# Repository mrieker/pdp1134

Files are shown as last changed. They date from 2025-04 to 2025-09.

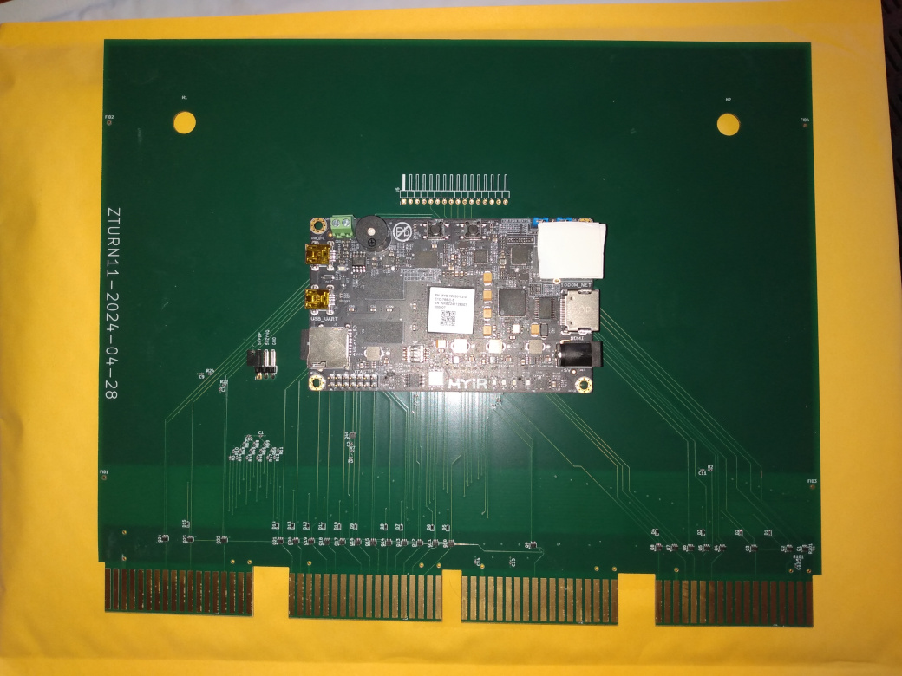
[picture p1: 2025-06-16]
boardpic.jpg

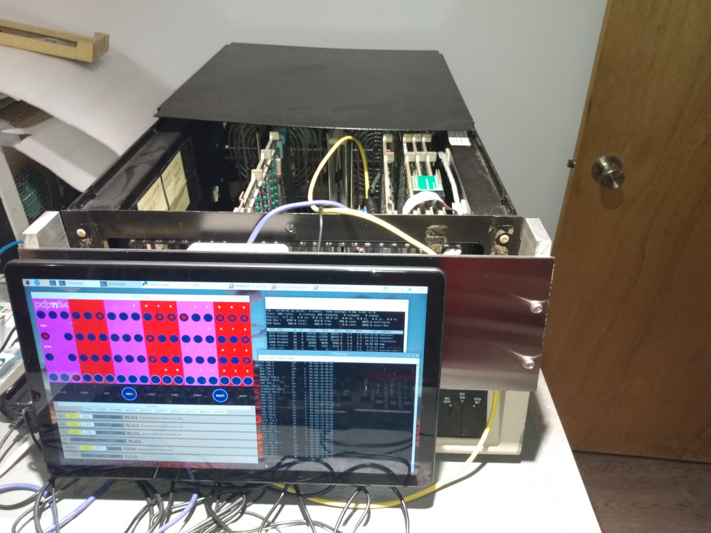
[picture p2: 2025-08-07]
runningpic.jpg

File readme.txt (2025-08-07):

FPGA/ARM board that plugs into Unibus on PDP-11/34.

Provides functionality of the KY-11 console, 124KW memory,
RL-11 disks (RL01/RL02), DL-11 serial port, KW-11 line clock,
RH-11 disks (RP04/RP06), TM-11 tape drive, DELUA ethernet,
PC-11 paper tape reader/punch, DZ-11 serial line mux.

Also contains a PDP-11/34 processor simulator so can test
software without having real processor.

Has a GUI interface (ccode/z11gui) as well as a TCL command line
interface (ccode/z11ctrl) for scripting.

See howto.txt for more information.

Pics of board and gui screen are in boardpic.jpg and guittypic.png,
runningpic.jpg is pic of 10.5" screen mounted on front of PDP-11/34
with Zynq in place of console board.

It uses a ZTurn Zynq 7020 board for the FPGA/ARM processor,
memory, SDCARD, ethernet.  The ARM processor runs the
Raspberry PI OS, with a kernel specific to the Zynq.

The board might work on other PDP-11s, I haven't tested it
with anything else.  The only thing that makes it '34 specific
are the two halt signals.  Other than that, it is just another
Unibus compatible device, fitting in a quad-sized SPC slot.

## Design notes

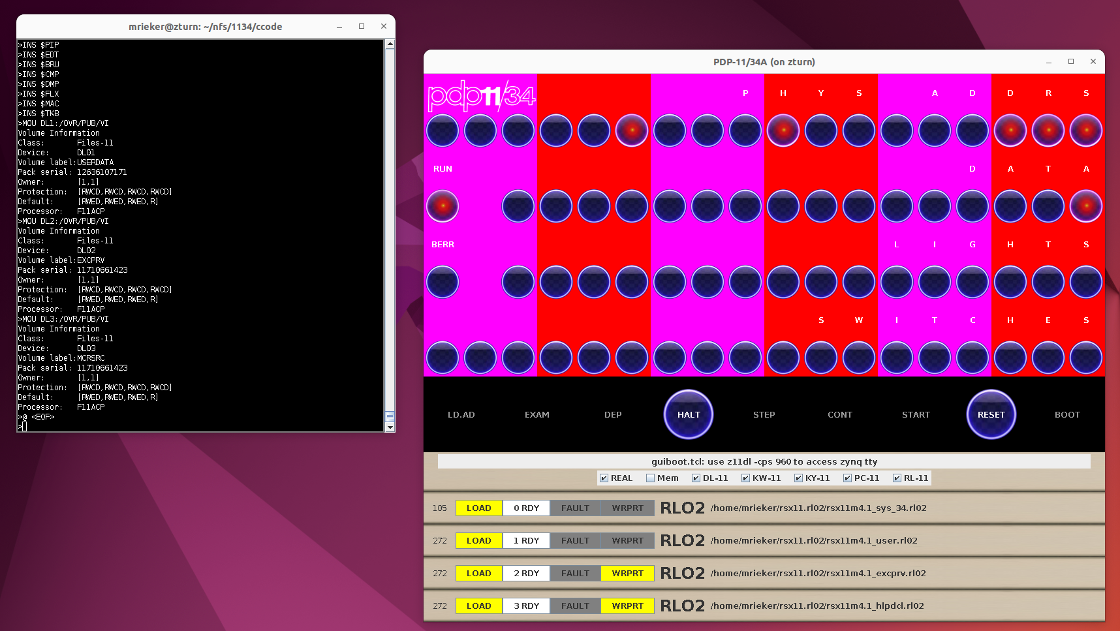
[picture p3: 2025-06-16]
guittypic.png

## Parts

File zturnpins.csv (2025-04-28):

J11-09 | B13-LN11 | V7
J11-13 | B13-LN12 | U10
J11-19 | B13-LN13 | Y6
J11-18 | B13-LN14 | Y8
J11-23 | B13-LN15 | W8
J11-22 | B13-LN21 | V10
J11-07 | B13-LP11 | U7
J11-11 | B13-LP12 | T9
J11-17 | B13-LP13 | Y7
J11-16 | B13-LP14 | Y9
J11-21 | B13-LP15 | V8
J11-20 | B13-LP21 | V11
J11-28 | B34-LN01 | T10
J11-29 | B34-LN02 | U12
J11-32 | B34-LN03 | V13
J11-33 | B34-LN04 | W13
J11-38 | B34-LN05 | T15
J11-39 | B34-LN06 | R14 | LED-RED
J11-42 | B34-LN07 | Y17 | LED-BLU
J11-43 | B34-LN08 | Y14
J11-47 | B34-LN11 | U15
J11-26 | B34-LP01 | T11
J11-27 | B34-LP02 | T12
J11-30 | B34-LP03 | U13
J11-31 | B34-LP04 | V12
J11-36 | B34-LP05 | T14
J11-37 | B34-LP06 | P14
J11-40 | B34-LP07 | Y16 | LED-GRN
J11-41 | B34-LP08 | W14
J11-45 | B34-LP11 | U14 | 12MHz OSC
J12-25 | B35-LN01 | B20
J12-24 | B35-LN02 | A20
J12-29 | B35-LN03 | D18
J12-28 | B35-LN04 | D20
J12-35 | B35-LN05 | E19
J12-34 | B35-LN06 | F17
J12-39 | B35-LN07 | M20
J12-38 | B35-LN08 | M18
J12-45 | B35-LN09 | L20
J12-44 | B35-LN10 | J19
J12-49 | B35-LN11 | L17
J12-48 | B35-LN12 | K18
J12-55 | B35-LN13 | H17
J12-54 | B35-LN14 | H18
J12-59 | B35-LN15 | F20
J12-58 | B35-LN16 | G18
J12-65 | B35-LN17 | H20
J12-64 | B35-LN18 | G20
J12-69 | B35-LN19 | G15
J12-68 | B35-LN20 | J14
J12-75 | B35-LN21 | N16
J12-74 | B35-LN22 | L15
J12-79 | B35-LN23 | M15
J12-78 | B35-LN24 | J16
J12-23 | B35-LP01 | C20
J12-22 | B35-LP02 | B19
J12-27 | B35-LP03 | E17
J12-26 | B35-LP04 | D19
J12-33 | B35-LP05 | E18
J12-32 | B35-LP06 | F16
J12-37 | B35-LP07 | M19
J12-36 | B35-LP08 | M17
J12-43 | B35-LP09 | L19
J12-42 | B35-LP10 | K19
J12-47 | B35-LP11 | L16
J12-46 | B35-LP12 | K17
J12-53 | B35-LP13 | H16
J12-52 | B35-LP14 | J18
J12-57 | B35-LP15 | F19
J12-56 | B35-LP16 | G17
J12-63 | B35-LP17 | J20
J12-62 | B35-LP18 | G19
J12-67 | B35-LP19 | H15
J12-66 | B35-LP20 | K14
J12-73 | B35-LP21 | N15
J12-72 | B35-LP22 | L14
J12-77 | B35-LP23 | M14
J12-76 | B35-LP24 | K16
J11-51 | LCD-DATA00 | T16
J11-53 | LCD-DATA01 | U17
J11-46 | LCD-DATA02 | V15
J11-48 | LCD-DATA03 | W15
J11-55 | LCD-DATA04 | U18
J11-57 | LCD-DATA05 | U19
J11-50 | LCD-DATA06 | N18
J11-52 | LCD-DATA07 | P19
J11-59 | LCD-DATA08 | N20
J11-61 | LCD-DATA09 | P20
J11-56 | LCD-DATA10 | T20
J11-58 | LCD-DATA11 | U20
J11-63 | LCD-DATA12 | V20
J11-65 | LCD-DATA13 | W20
J11-60 | LCD-DATA14 | Y18
J11-62 | LCD-DATA15 | Y19
J11-64 | LCD-DE | R16
J11-69 | LCD-HSYNC | W16
J11-66 | LCD-PCLK | R17
J11-70 | LCD-VSYNC | V16

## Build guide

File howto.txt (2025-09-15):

Basic configurations:

    1) real without console -
        KY-11 console M7859 removed (leds dark but power switch works)
        ZTurn plugged into primary backplane (so it has access to halt lines)
        All console functions handled via GUI or TCL commands

    2) real with console -
        KY-11 console M7859 installed
        ZTurn connected to Unibus theoretically anywhere
        Only RESET and BOOT functions available via GUI and TCL
        All other console functions handled via KY-11 keypad

    Simulator will work with either of the above configurations.  It
    will ignore anything coming in from the Unibus and not output
    anything to the Unibus.  It will run with the processor power on
    or off, and will run on a ZTurn board not plugged into anything.

--------

Quickstart guide:

    Set up SDCARD for ZTurn board:

        see zplin/quicksdcard.txt

        * copy 32-bit raspi os to an SD card
        * delete all files from /boot partition then replace with
            just BOOT.BIN and image.ub from the zynq directory
        * boot zturn and configure to taste

        * clone repo to non-priv user (sudo should not require password)
        * cd 1134/ccode ; make

    These instructions apply only if the M7859 console board is installed and working:

        Use z11ctrl command to load media files in FPGA provided drives:

        $ ./z11ctrl
        z11ctrl> source $Z11HOME/boots.tcl  ;# get some boot related functions
        z11ctrl> pin set fpgamode 2         ;# connect FPGA to real Unibus
        z11ctrl> probedevsandmem            ;# turn on fpga devices and memory to fill in missing real devices and memory
        z11ctrl> rlload 0 somefile.rl02     ;# load a file in RL02 drive 0 (will also accept .rl01 files)
                                            ;# there is also rhload (RP04/RP06) and tmload (TU10)

        Then use the 11/34 keypad to boot the disk.
        If the boot rom does not contain RL boot code:

        z11ctrl> rlboot                     ;# or rhboot, tmboot

        Either way, if the Z11 is providing the console tty:

        z11ctrl> exit
        $ ./z11dl

    These instructions apply only if there is no M7859 console board installed:

        To boot the 11/34 via GUI:

            $ ./z11gui &
                select REAL or SIM mode by clicking the OFF checkbox

                check other checkboxes for devices you want the FPGA to provide
                for REAL mode,
                    the Mem checkbox will fill in whatever memory is missing up to 124KW
                    other than Mem, do not check anything that you have a real board for
                        (or they will stomp on each other)
                for SIM mode,
                    the Mem checkbox will provide the whole 124KW memory
                    check any other devices wanted (all are fine)

                load boot media (RP04/6, RL01/2, TU10) with appropriate LOAD button
                the boot menu will only boot from drive 0

                load any other media files wanted.  note the gui only provides access
                to drives 0 and 1.  to access the other drives, use the command line
                utility, z11ctrl, rlload/rhload/tmload commands as shown under the
                boot via command line section below.

                click the BOOT button
                    (runs script guiboot.sh)

            $ ./z11dl       to access Zynq-provided tty port
                only if the DL-11 checkbox is checked

            should see a boot menu on TTY when BOOT button was clicked

        To boot the 11/34 via command line:

            $ ./z11ctrl
            z11ctrl> pin set fpgamode 1         ;# select SIM mode
                or
            z11ctrl> pin set fpgamode 2         ;# select REAL mode

            z11ctrl> source $Z11HOME/boots.tcl  ;# get some boot scripts
            z11ctrl> probedevsandmem            ;# fill in any missing devices and memory

            if you do not have a real RL-11 controller or are using SIM mode,
                rlload 0 [-readonly] somefile.rl02      ;# bootable disk image (can use .rl01 file)
                rlload 1 [-readonly] otherfile.rl02     ;# as needed (can use .rl01 file)
                    can also do drives 2 and 3

            or use rhload to load RP04/RP06 file, or tmload to load .tap-format tape file

            z11ctrl> rlboot                     ;# boot rl drive 0
                or rhboot for rh drive 0, tmboot for tm drive 0
            z11ctrl> exit                       ;# close command-line program, PDP and/or FPGA still running

            $ ./z11dl       to access Zynq tty port
                only if the DL-11 checkbox is checked

            Note:

                You can put the z11ctrl commands in a file, eg myboot.tcl,
                with your customized rlload commands.  Do not include the
                'exit' command.

                The z11dl program (if needed) can be run from TCL with:

                    exec -ignorestderr ./z11dl < /dev/tty > /dev/tty

                ...so it can be at the end of myboot.tcl.

                Then run the script with './z11ctrl myboot.tcl'.  

        Note:
            You can run the GUI (z11gui) and TCL (z11ctrl) programs
            at the same time.  The GUI will pick up any state changes
            made by a TCL script and the TCL script can sense any changes
            made by the GUI.

            This is possible because all state is kept in shared memory
            and FPGA registers which are also common to all processes.

--------

The FPGA contains circuits for:

    DELUA ethernet controller
    DL-11 console TTY
    DZ-11 terminal multiplexer
    KW-11 line clock
    KY-11 11/34 console
    RH-11 disk controller
    RL-11 disk controller
    TM-11 tape controller
    Main memory with parity controller (124KW selectable in 4KB chunks)
    Boot memory (address range 760000..7777777 selectable in 512B chunks)

    The FPGA also has a PDP-11/34 simulator so software can be developed
    without requiring the real 11/34.

The Zynq chip used contains two major parts:  an FPGA and an ARM processor.
The FPGA code interfaces with the ARM processor via a 4KB page consisting of
1024 32-bit registers.  Those registers are divided into sections.  The first
register of each section is a 32-bit read-only descriptor telling what the
section is for.  The descriptors all have this format:

    <31:16> = two ascii characters naming the section
                "11" - main registers for controlling the FPGA and simulator
                "BM" - block memory, up to 124KW main memory, plus boot memory
                "DL" - DL-11 serial line registers
                "DZ" - DZ-11 serial line multiplexer registers
                "KW" - KW-11 line clock registers
                "KY" - KY-11 console registers
                "RH" - RH-11 controller registers
                "RL" - RL-11 controller registers
                "TM" - TM-11 controller registers
                "XE" - DELUA controller registers

    <15:12> = log2 of number of 32-bit registers in the section
                (including descriptor register):
                    0 =  2 registers
                    1 =  4 registers
                    2 =  8 registers
                    3 = 16 registers
                    4 = 32 registers
                        etc

    <11:00> = version information

Any unused registers read as DEADBEEF.

The format of the remaining registers of a section are dependent on what the
section is for.  It can be a bit messy, but in general for the I/O devices,
the PDP visible registers will be in there along with any other needed control
bits (such as an 'enable' bit which connects the board to the Unibus).
The BM section has an enable bit for each 4KB block of memory so they can be
individually enabled, and there are registers for giving the ARM direct access
to the memory.  Details of the sections can be found in the corresponding .v
source file, like pick dl11.v for a simple one.

You can see what sections are present with:

    ./z11dump -once     # dump contents of 4KB FPGA register page
                        # can be run at any time to show state of FPGA

The ARM part of the Zynq chip runs Raspberry PI OS (or probably any Linux you
could get to run on it).  It has a kernel specific to the Zynq chip but the
filesystem is from a RasPI.

There are a few programs that run on the ARM (under Linux) that control the
FPGA via that 4KB register page:

    z11ctrl     - main control program
                  provides TCL scripting of all functions

    z11rl       - processes RL-11 disk I/O instructions,
                  accessing the simulated RL01/RL02 disk files
                  it runs as a daemon automatically started when the GUI
                  or a TCL script accesses the RL-11 controller

    z11rh       - likewise for RH-11 disk (RP04/RP06)
    z11tm       - likewise for TM-11 tape (TU10)

    z11xe       - processes DELUA ethernet I/O instructions,
                  passing packets between the PDP and the Zynq's ethernet

    z11dl       - processes DL-11 tty I/O instructions,
                  passing input/output to the tty it is being run from
                  must be manually started to access the DL-11 port

    z11dz       - processes DZ-11 tty I/O instructions for a single line,
                  passing input/output to the tty it is being run from

    z11dump     - dumps out the FPGA/ARM interface registers
                  can be left to run contonuously to keep a screen updated

    z11gui      - a blinking-lights panel with various usual PDP-11 type
                  lights, switches and buttons

There are 4 modes the FPGA can be in:

    0 = OFF     - The FPGA hi-Zs all its outputs to the Unibus and ignores any
                  input from the Unibus.  Also, none of its I/O devices will do
                  anything.

    1 = SIM     - The FPGA again hi-Zs all its outputs to the Unibus and
                  ignores any input from the Unibus.  However, the internal
                  PDP-11/34 simulator circuit is turned on and the FPGAs I/O
                  devices can be turned on.  It will act just like a real PDP
                  (no FPU though), with the I/O devices internal to the FPGA.

    2 = REAL    - The FPGA will output to the Unibus and process inputs from
                  the Unibus.  It is assumed there is a PDP on the Unibus, but
                  there does not have to be anything else (except for
                  terminators).

    3 = MAN     - The FPGA will process manual control of the Unibus pins and
                  its internal devices will be disabled.  This mode is only used
                  for testing the circuit board pins one at a time.  There is a
                  test script edgepintest.tcl that uses this mode.

On power up, the FPGA is in OFF mode.

To control the mode, use either z11ctrl or z11gui.  z11ctrl uses a TCL interpreter
to process commands, and you can simply type in commands as well as script them.
There are several scripting examples in the ccode directory.  To select real mode,
use 'pin set fpgamode 2', to select sim mode, use 'pin set fpgamode 1'.  'pin get
fpgamode' will return what mode it is in.  For the GUI, click the OFF checkbox then
select REAL or SIM.

There are a few commands that z11ctrl has added to the standard TCL commands that
provide access to the FPGA.  To list out all the z11ctrl-specific commands, type help:

    $ ./z11ctrl
    z11ctrl> help

One example is the 'pin' command.  It can get and set various bits in the FPGA
register page.  To get a list of all pins available to the pin command:

    z11ctrl> pin list

To set the mode:

    z11ctrl> pin set fpgamode 1         ;# use simulator, no real Unibus access
    z11ctrl> pin set fpgamode 2         ;# connect FPGA to real Unibus and PDP

To query the current mode:

    z11ctrl> pin get fpgamode           ;# the 'get' keyword is optional
    2

To toggle in a simple program:
    Note:  Won't work on real PDP with KY-11 M7859 board installed
        as the M7859 hogs the Unibus when the processor is halted.

    z11ctrl> pin set fpgamode 1 or 2    ;# 1 for simulator; 2 for real pdp
    z11ctrl> hardreset                  ;# make sure sim or pdp is reset and halted
    z11ctrl> enabmem                    ;# make sure we have some memory
                                        ;# - if sim, turns on all FGPA memory (124KW)
                                        ;# - if real, pads real mem to 124KW
                                        ;# wrword,rdword use dma cycles to access memory when processor is running
                                        ;# - if processor is halted, they revert to using examine/deposit cycles
    z11ctrl> wrword 0100 05200          ;# INC R0
    z11ctrl> wrword 0102 00776          ;# BR 0100
    z11ctrl> flickstart 0100            ;# start it running
    z11ctrl> flickstep                  ;# step it (causes it to halt)
    66                                  ;# prints PC in decimal
    z11ctrl> octal [flickstep]          ;# step it again, print PC in octal
    000100
    z11ctrl> octal [rdword 0777700]     ;# read R0 then display in octal
    065321
    z11ctrl> flickcont                  ;# continue it
    z11ctrl> flickstep                  ;# halt it
    66
    z11ctrl> octal [rdword 0777700]     ;# read R0 then display in octal
    142356
    z11ctrl> octal [rdword 0777707]     ;# read PC then display in octal
    000102                              ;# - should numerically match what flickstep returned

Other pins of interest:

    Set these pins to 1 to enable FPGA device, 0 to disable
    (equivalent of plugging/unplugging board from Unibus):

        dl_enable - DL-11 console tty controller
        kw_enable - KW-11 line clock
        ky_enable - 777570 light & switch registers
        rl_enable - RL-11 disk controller

Do not enable an FPGA device if in REAL mode and there is that same device on the Unibus.
It won't damage anything (the Unibus is open-collector), but they will stomp on each other.
They won't stomp on each other in SIM mode because the FPGA is disconnected from the Unibus.

So this sequence works in REAL mode only if the real KY-11 M7859 board is removed from the Unibus.
It also works in SIM mode.

    z11ctrl> pin set ky_enable 1        ;# enable FPGA 777570 lights and switches registers
    z11ctrl> pin set kw_switches 012345 ;# set switch register
    z11ctrl> octal [rdword 0777570]     ;# do a dma/examine cycle to read the switch register
    012345
    z11ctrl> wrword 0777570 054321      ;# do a dma/deposit cycle to write the light register
    z11ctrl> octal [pin get ky_lights]  ;# get light register
    054321
    z11ctrl>

Enabling memory is a bit more involved.  It is 124KW with individual bits for each 4KB.
If in REAL mode with no memory or in SIM mode, this will turn on all 124KW:

    z11ctrl> pin set bm_enablo 0xFFFFFFFF   ;# turns on addresses 000000..377777
    z11ctrl> pin set bm_enabhi 0x3FFFFFFF   ;# turns on addresses 400000..757777

If in REAL mode and the PDP has 32KW memory, this will fill it to 124KW:

    z11ctrl> pin set bm_enablo 0xFFFF0000   ;# turns on addresses 200000..377777 (turns off 000000..177777)
    z11ctrl> pin set bm_enabhi 0x3FFFFFFF   ;# turns on addresses 400000..757777

If in REAL mode and the PDP has 80KW memory, this will fill it to 124KW:

    z11ctrl> pin set bm_enablo 0            ;# turns off addresses 000000..377777
    z11ctrl> pin set bm_enabhi 0x3FFFFF00   ;# turns on addresses 500000..757777 (turns off 400000..477777)

If in REAL mode and you only want to use the real memory (turns off all FPGA memory):

    z11ctrl> pin set bm_enablo 0 bm_enabhi 0

--------

The rdword and wrword commands read and write Unibus locations using DMA cycles.
If the processor is halted, they use examine/deposit cycles instead (basically
same as regular DMA cycles but without the NPR/NPG sequence), just like the real
KY-11 console board.

If the Zynq is in REAL mode and the KY-11 is installed and the processor is
halted, the KY-11 will hog the bus by holding BBSY asserted.  So this blocks
the Zynq from accessing the Unibus, and rdword, wrword will fail.

--------

If you have a PiDP-11 handy, you can connect it up to the 11/34 and use it for
a blinkenlights console.

 1) Remove M7859 console board from 11/34 if present.  Make sure the CA1-CB1
    NPG grant jumper wire is in place and the BG grant jumper card is in place
    if the slot is left empty.

On the Zynq:

 2) Start the PiDP server with './z11pidp server &'.

    It listens on UDP port 5826.

On the Raspberry PI plugged into the PiDP-11:

 1) Stop all PiDP software on the Raspberry PI.
 2) Clone the 1134.git repo then do a make from the ccode directory.
 3) Run it with './z11pidp client <zynqhostname> &'

    It transmits switches to the server on UDP port 5826 and listens
    for updates to the lights in a continuous loop.

To test that the UDP packets get through, lift the white lamp test
switch.  It should do a 'race track' pattern with the lights.

You will still need to use z11ctrl or z11gui to load files in the
disk and tape drives.

Read the comments at the top of z11pidp.cc for details about the lights
and switches.  They pretty much behave as expected.  The only significant
deviations are:

    1) have to turn on SW<21> for the switches to work as 777570 switch
       register, otherwise have to use z11ctrl 'pin set ky_switches 0<value>'
       or the z11gui switches to set the 777570 switch register

    2) ADDRESS<20> light indicates Zynq is in sim mode
       ADDRESS<21> light indicates Zynq is in real mode

       If both lights are off, means the Zynq is in OFF mode and needs to
       be turned on with z11ctrl or z11gui.

--------

FYI, there is a stand-alone memory test program that will pound the daylights out of
whatever memory is accessible, real or FPGA:

    ./memtest.armv7l <lowaddress> <highaddress>

  eg, to test the first 16KW:

    ./memtest.armv7l 0 077777

It writes random numbers then reads them back using DMA cycles, writing random
numbers from time to time.  Since it uses DMA cycles with the processor halted,
it won't work if the real KY-11 console board is plugged in the Unibus.

--------

There is a Verilator module used to develop FPGA code.  This allows running the
software on an X86-64 bit Linux computer using the Verilator Verilog-to-C++
translator.  It will process $display() calls in the Verilog code that you put
in for debugging.

 1) Install Verilator.  On Ubuntu, 'apt install verilator' will do.
 2) Compile the Verilator module:

    $ cd verisim
    $ make

    This will access the Verilog modules in the ../zynq directory.
    If you change the Verilog code, you need to rerun this make command.

 3) Run it

    $ ./verimain.x86_64

    Normally it does not output anythinng except printing its pid when it starts.
    It will display output from any $display() calls in the Verilog code.

From another screen:

 4) Build z11 software to access it.
    The make command will see that it is on an x86_64 and build everything to
    communicate with verimain.x86_64 instead of trying to access the FPGA.

    $ cd ../ccode
    $ make

 5) All the z11 programs (z11ctrl, z11dl, zz11dump, z11gui, etc) should now be
    available on the x86_64.  They run approx 50-100x slower than on the Arm/FPGA
    but otherwise behave the same.  For example you can run RSX or XXDP, you
    have to be a little patient.

--------

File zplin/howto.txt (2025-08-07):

########################################################################
#  How to set up tools for building Zynq FPGA code and create SD card  #
########################################################################

note:
    to create an sd card with the given fpga code, follow steps in quicksdcard.txt.
    if you want to make changes to the fpga code, follow the steps below.

start with:
    always needed:
        ZTurn 7020 board
        raspberry pi os install image (32-bit lite version)
        - bookworm (debian 12) is slow, bullseye (debian 11) is fast
        - ref: https://forums.raspberrypi.com/viewtopic.php?t=6019 -- bug mentioned halfway down

    to compile FPGA code:
        ubuntu 16.04
        vivado 2018.3 installed in /tools/Xilinx/Vivado/2018.3/bin/vivado
        petalinux 2018.3 in /tools/Xilinx/Downloads/petalinux-v2018.3-final-installer.run
        ./zturn_7z020_hdmi.bsp
        ./vdmahdmi.patch

        also make sure board_files/zturn-7z020 is in place in vivado tree
            /tools/Xilinx/Vivado/2018.3/data/boards/board_files/zturn-7z020
        untar ./zturn-7z020-board-files.tgz if not there

        must use Vivado 2018.3 cuz of bsp file supplied by MYIR

##############################
#   build petalinux kernel   #
##############################

    This creates a new boot file with default FPGA code (BOOT.BIN) and kernel image (image.ub).
    You can skip this section and use the provided images in ../zynq/BOOT.BIN and image.ub.

sudo ...
    apt install tofrodos iproute gawk gcc git-core make net-tools ncurses-dev \
        libncurses5-dev tftpd-hpa zlib1g-dev flex bison lib32z1 lib32ncurses5 lib32stdc++6 libselinux1
    apt install build-essential
    apt install chrpath socat autoconf libtool texinfo gcc-multilib
    apt install libsdl1.2-dev libglib2.0-dev
    apt install openssl-dev
    apt install libssl-dev
    apt install openssl
    apt install zlib1g:i386

    dpkg-reconfigure dash      << select <No>

# https://www.instructables.com/Getting-Started-With-PetaLinux/

[[ do the whole thing from medium-sized xterm ]]

cd .../pdp8l/zplin              # ie, directory containing this howto.txt
/tools/Xilinx/Downloads/petalinux-v2018.3-final-installer.run `pwd`/petadevel   # 11m56
    q y <Enter> q y <Enter> q y <Enter>    to skip licenses

source petadevel/settings.sh
source /tools/Xilinx/Vivado/2018.3/settings64.sh

mkdir petakernl
cd petakernl
petalinux-create -t project -s ../zturn_7z020_hdmi.bsp  # 1m05
cd zturn
petalinux-config    # 1m35 (just select <Exit> at the bottom)
petalinux-build     # 5m44
petalinux-package --boot --force --fsbl ./images/linux/zynq_fsbl.elf --fpga ./images/linux/system.bit --u-boot

cd build/tmp/work-shared/plnx-zynq7/kernel-source
patch -p1 < ../../../../../../../vdmahdmi.patch
    to disable VDMA and HDMI  (don't have fpga source for hdmi stuff)

    - unpatched xilinx_vtc.c 20094 bytes
        patched xilinx_vtc.c 19220 bytes

cd ../../../../..               (ie, petakernl/zturn)

petalinux-config -c kernel
    Device Drivers --->
        DMA Engine Support --->
            Xilinx DMA Engines [off]
            Xilinx AXI DMAS Engine [off]
petalinux-build     3m36                            # let it fail to compile vdmafb.c

cd build/tmp/work-shared/plnx-zynq7/kernel-source
patch -p1 < ../../../../../../../vdmahdmi.patch     # second time
cd ../../../../..               (ie, petakernl/zturn)
petalinux-build     4m52                            # it should succeed

petalinux-build -c kernel -x compile -f             # 0m29
petalinux-build                                     # 1m57
petalinux-package --boot --force --fsbl ./images/linux/zynq_fsbl.elf --fpga ./images/linux/system.bit --u-boot
ls -l images/linux/BOOT.BIN                         # contains default FPGA code
ls -l images/linux/image.ub                         # linux kernel

if edit kernel sometime:
    petalinux-build -c kernel -x compile -f
    petalinux-build

###################
#  Set up SDCARD  #
###################

    Sets up SDCARD with the BOOT.BIN and image.ub suitable for the Zynq
    Uses raspi filesystem.

# put blank sdcard in pc, comes up as something like /dev/sda
# replace /dev/sda in the commands below with whatever the sdcard really is

df                  # see if sdcard got automounted
umount /dev/sda1    # umount if so
umount /dev/sda2 ...etc

# copy raspi sdcard image to sdcard
xzcat 2024-10-22-raspios-bullseye-armhf-lite.img.xz | dd of=/dev/sda status=progress
partprobe /dev/sda

# replace raspi kernel with zturn kernel
# - use either the BOOT.BIN,image.ub created above or use those from ../zynq directory
mkdir /x
mount /dev/sda1 /x
rm -rf /x/*
cp images/linux/BOOT.BIN /x/
cp images/linux/image.ub /x/
umount /x

# expand root partition to whole sdcard
parted /dev/sda
  resizepart 2 -1s
  quit
resize2fs /dev/sda2

# remove root and pi passwords for now
mount /dev/sda2 /x
edit /x/etc/shadow              (use whatever editor you like)
  remove * or ! from root and pi line password field

# set up hostname
echo zturn > /x/etc/hostname    (or whatever you want for hostname)
edit /x/etc/hosts
  change raspberrypi to whatever was put in /x/etc/hostname

# copy kernel source so modules will compile
mkdir -p /x/usr/src/linux-headers-4.14.0-xilinx-v2018.3
rsync -av petakernl/zturn/build/tmp/work-shared/plnx-zynq7/kernel-source/ /x/usr/src/linux-headers-4.14.0-xilinx-v2018.3
rsync -av petakernl/zturn/build/tmp/work-shared/plnx-zynq7/kernel-build-artifacts/ /x/usr/src/linux-headers-4.14.0-xilinx-v2018.3
chown root:root -R /x/usr/src

# done filling sdcard
umount /x       may take a long time to flush to sdcard (30min)
rmdir /x

############################
#  Boot ZTurn from SDCARD  #
############################

connect usb serial cable from pc to zturn (115200 baud) and use terminal program to access
insert sdcard and boot zturn
login as root (or as pi then sudo bash to get root)

on zturn:
  as root:
    raspi-config -> Interface Options -> SSH -> Yes
    passwd   to set root and pi passwords so ssh will work

    optionally set up static IP address:
      edit /etc/dhcpcd.conf
      uncomment static ip configuration section
      reboot

    apt install libreadline-dev
    apt install libx11-dev
    apt install tcl8.6-dev
    apt install git
    apt install bc

    mkdir -p /lib/modules/4.14.0-xilinx-v2018.3
    ln -s /usr/src/linux-headers-4.14.0-xilinx-v2018.3 /lib/modules/4.14.0-xilinx-v2018.3/build

    cd /usr/src/linux-headers-4.14.0-xilinx-v2018.3
    edit scripts/dtc/dtc-lexer.lex.c_shipped
      Find the line 'YYLTYPE yylloc;' and change it to 'extern YYLTYPE yylloc;'
      reference : https://lkml.org/lkml/2020/4/1/1206
    make oldconfig          # 0m38
    make prepare            # 0m31
    make modules_prepare    # 1m28

  as pi:
    git clone .../pdp8l.git
    cd pdp8l/pipan8l
    make   (may need to change -ltcl to -ltcl8.6 in the makefile)
    ./z8lsim
      if Bus error - means the BOOT.BIN has default FPGA contents so do next section
      if z8lsim> prompt - means our PDP-8/L code is loaded in FPGA
    z8lsim> source testmem.tcl
    z8lsim> looptest testrands
        ...  control-C to stop test
    z8lsim> exit

######################################
#  Put PDP-8/L FPGA file onto ZTurn  #
######################################

    make sure can do ssh root@zturn from pc

then on zturn:
    ls -l /boot should show BOOT.BIN, image.ub files

    # ls -l /boot
    total 8456
    -rwxr-xr-x 1 root root 4688040 Dec  5 22:43 BOOT.BIN
    -rwxr-xr-x 1 root root 3967676 Dec  5 22:43 image.ub

then back on pc to compile FPGA code:
    cd .../pdp8l/zynq
    /tools/Xilinx/Vivado/2018.3/bin/vivado pdp8l.xpr
        do 'Generate Bitstream' to compile verilog to .bit file
    ./makebootbin.sh        make BOOT.BIN then copy to zturn and reboot

then ssh pi@zturn and do:
    cd pdp8l/pipan8l
    ./z8lsim
      if Bus error - means the BOOT.BIN still has default FPGA contents
      if z8lsim> prompt - means our PDP-8/L code is loaded in FPGA
    z8lsim> source testmem.tcl
    z8lsim> looptest testrands
        ...  control-C to stop test
    z8lsim> exit

All Done!

#########################################
#  FYI, how to create a Vivado project  #
#########################################

Use Z-turnBoard_Tutorial_Book.pdf
    - make sure board_files/zturn-7z020 is in place in vivado tree
      eg, /tools/Xilinx/Vivado/2018.3/data/boards/board_files/zturn-7z020
    - in left column, "Create Block Design"
    - add ZYNQ7 Processing System
    - do "Run Block Automation" to define and connect DDR, FIXED_IO ports
    - interconnect clocks FCLK_CLK0 -> M_AXI_GP0_ACLK, S_AXI_HP0_ACLK
    - add any Verilog/VHDL files & add as modules to block diagram
        keep them in top-level directory so Vivado doesn't bury them
    - create hardware wrapper
        "Sources" tab
        right-click the .bd file
        select "Create HDL Wrapper"
        "Let Vivado manage..."
        OK

    - Run Synthesis, but then do "Open Synthesized Design"
        - Window -> I/O Ports
        - Scalar ports
        - make pin assignments
        - click save (floppy) button in upper left to save as constraints file

    - Run Synthesis again to use new pin assignments
    - Run Implementation
    - Generate Bitstream

    - for git, have it ignore everything except:
      - your verilog/vhdl files (keep in top-level directory)
      - your .xdc file assigning pins etc
      - your .xpr file defining the project
      - your <board>/<board>.bd file defining top-level layout
      - your <board>/hdl/<board>_wrapper.vhd file

create a new BOOT.BIN -
    source petadevel/settings.sh
    source /tools/Xilinx/Vivado/2018.3/settings64.sh
    cd petakernl/zturn
    petalinux-package --boot --force --fsbl ./images/linux/zynq_fsbl.elf --fpga ***BITFILE***.bit --u-boot

...get BOOT.BIN from images/linux, copy to /boot/BOOT.BIN of ZTurn SD card then reboot

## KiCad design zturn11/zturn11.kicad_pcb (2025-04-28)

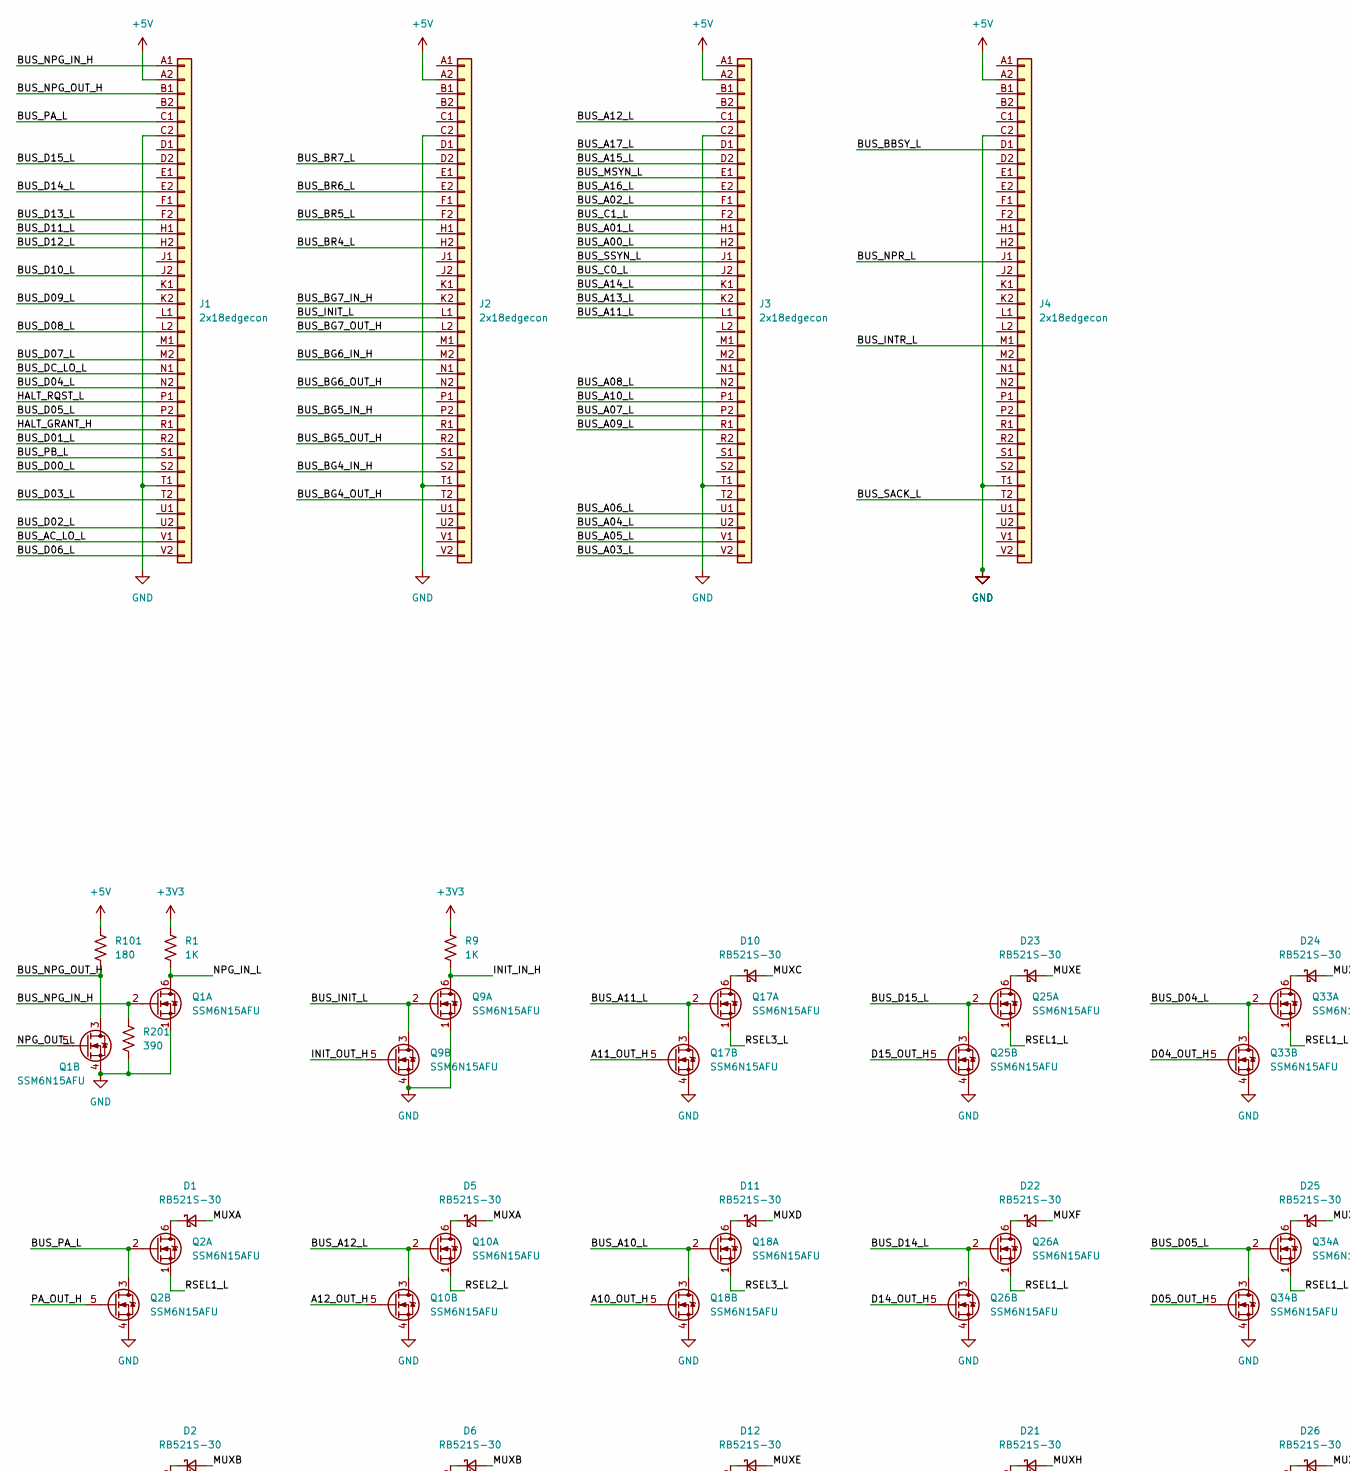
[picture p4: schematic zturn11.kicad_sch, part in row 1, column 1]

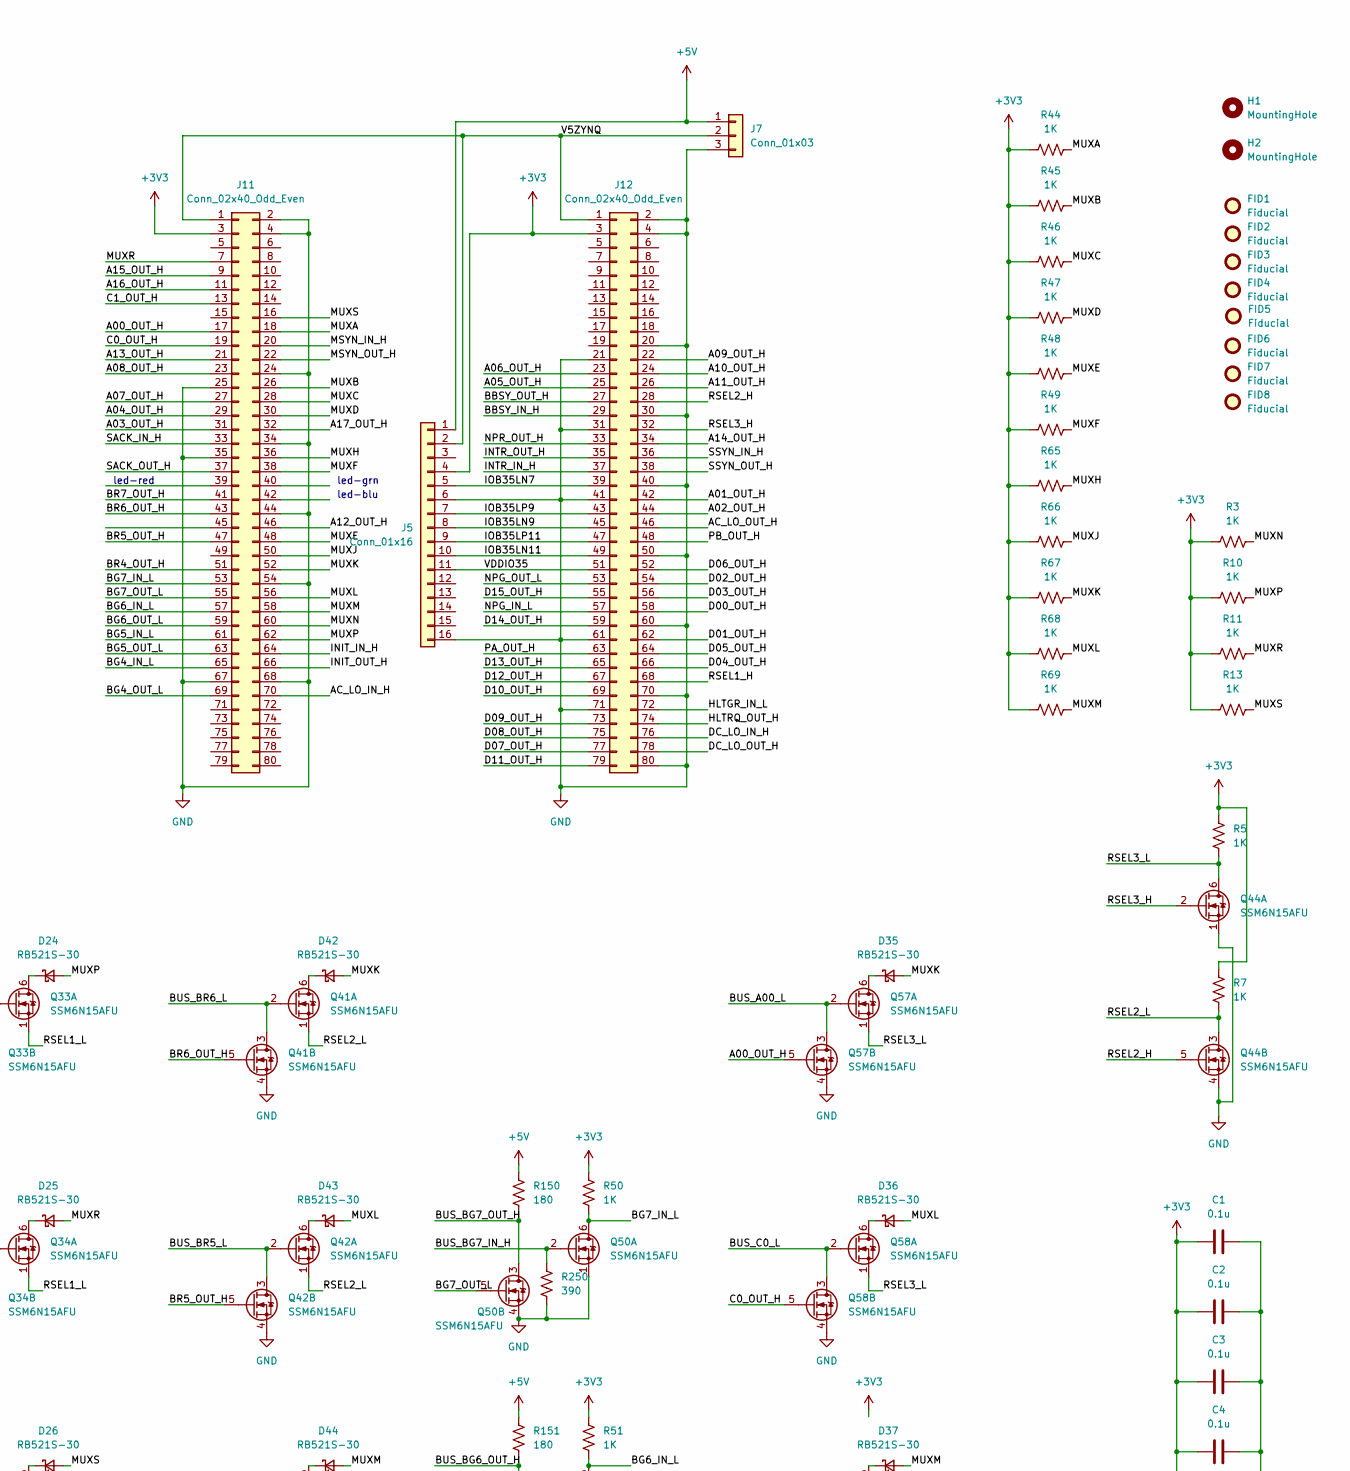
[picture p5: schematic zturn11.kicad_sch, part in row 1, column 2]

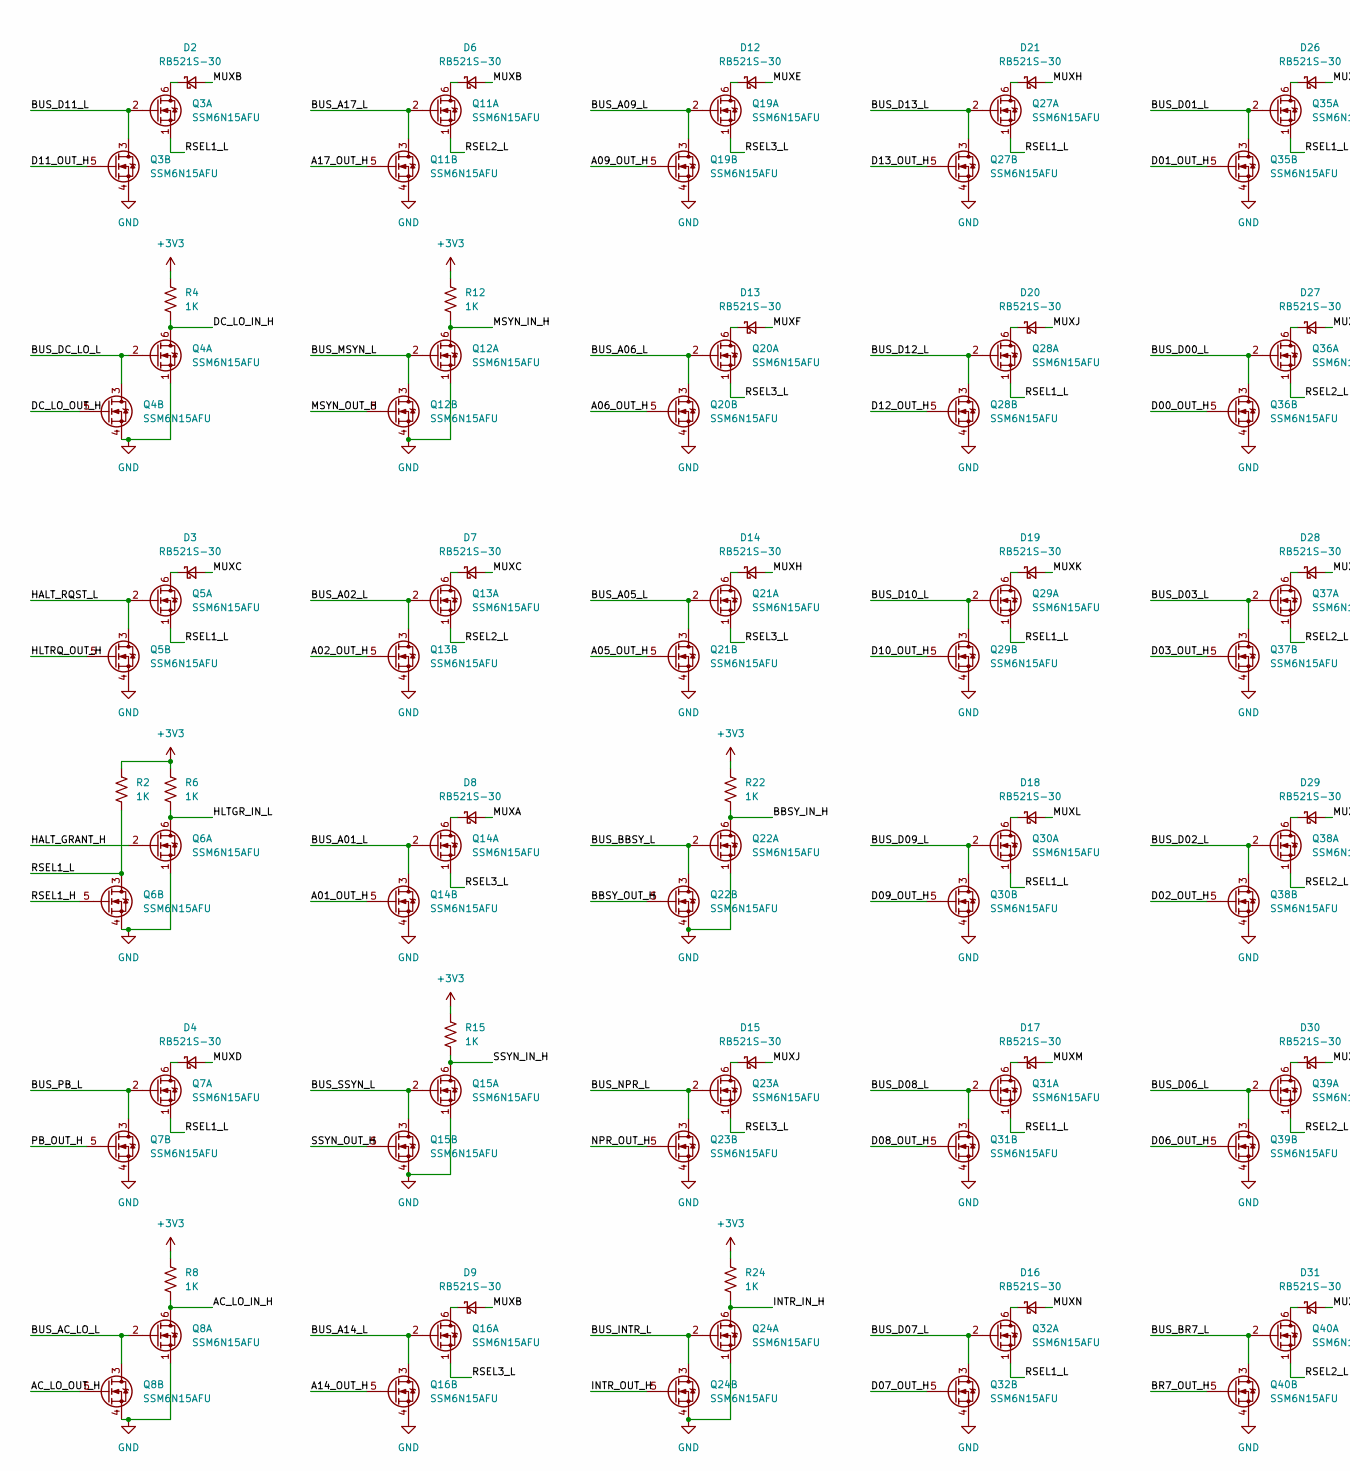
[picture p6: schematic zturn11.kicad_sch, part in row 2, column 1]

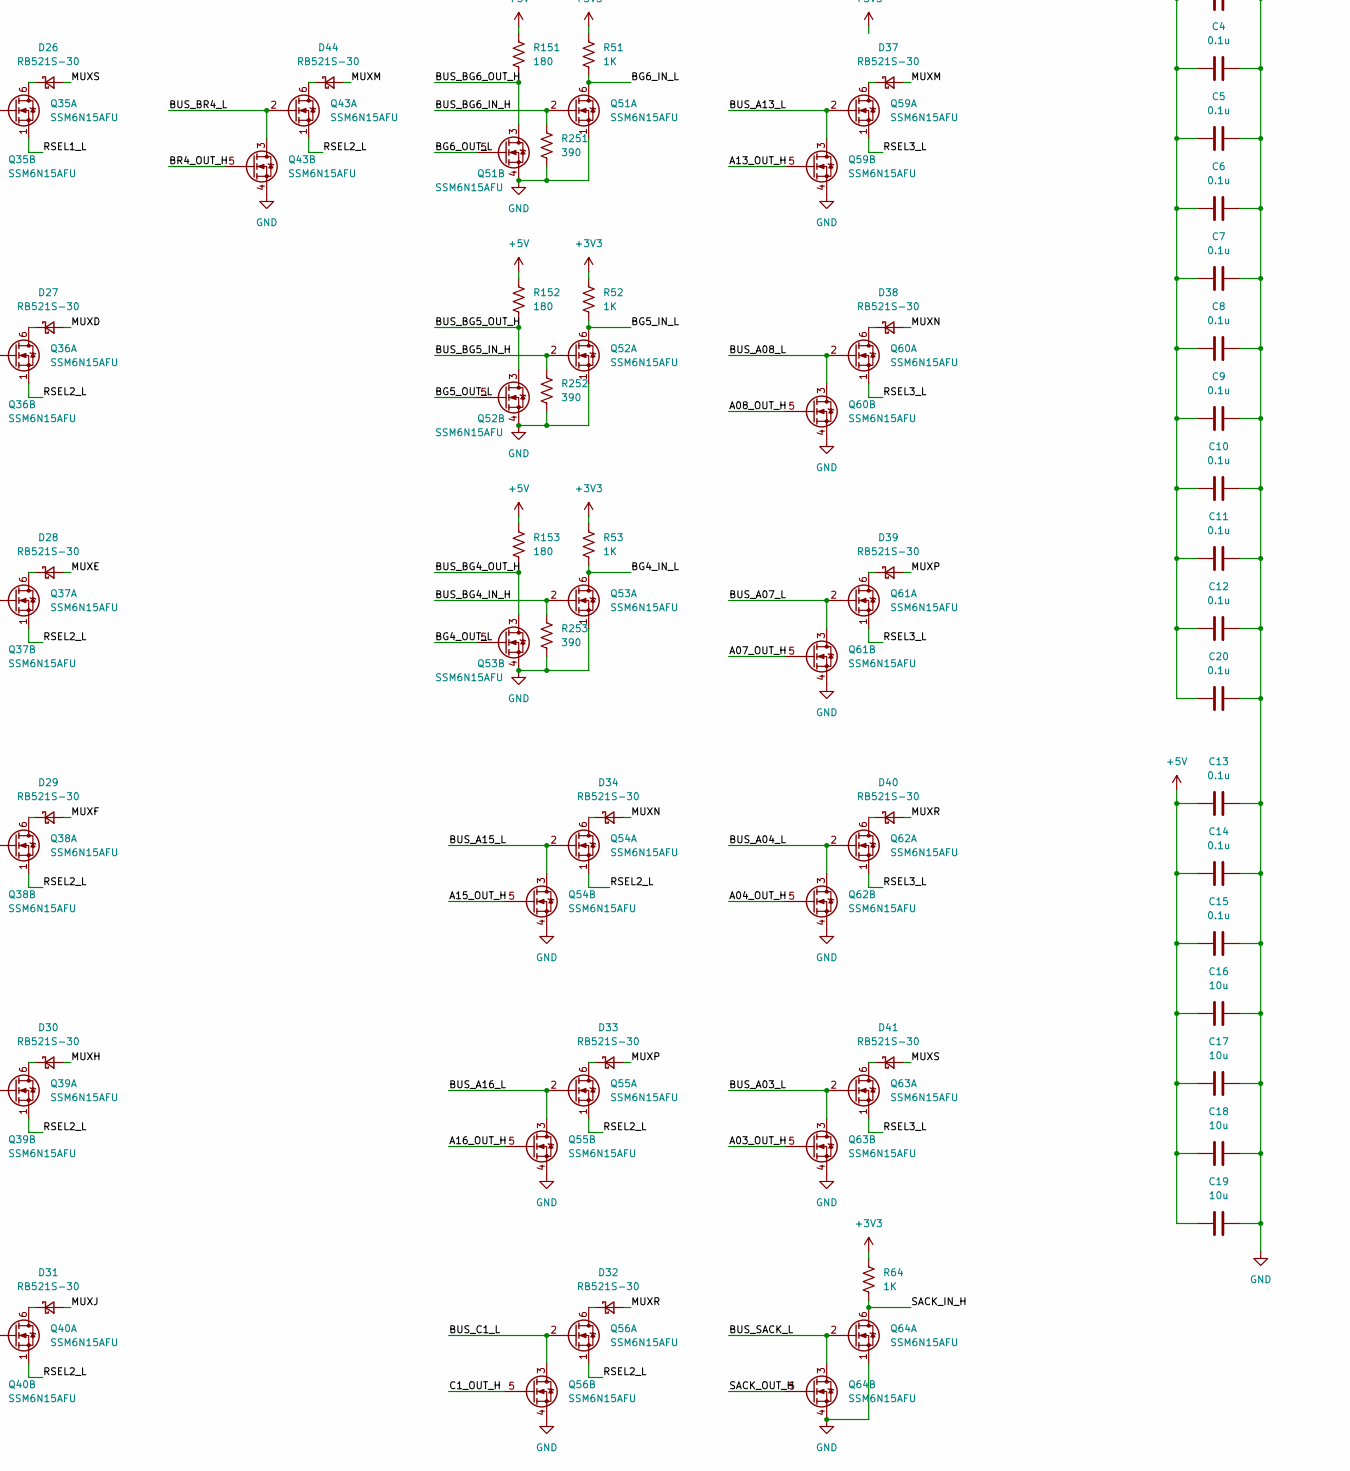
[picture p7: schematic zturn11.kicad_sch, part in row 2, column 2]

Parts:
C1, C2, C3, C4, C5, C6, C7, C8, C9, C10, C11, C12, C13, C14, C15, C20: 0.1u; C_0402_1005Metric
C16, C17, C18, C19: 10u; C_1206_3216Metric
D1, D2, D3, D4, D5, D6, D7, D8, D9, D10, D11, D12, D13, D14, D15, D16, D17, D18, D19, D20, D21, D22, D23, D24, D25, D26, D27, D28, D29, D30, D31, D32, D33, D34, D35, D36, D37, D38, D39, D40, D41, D42, D43, D44: RB521S-30; D_SOD-523
FID1, FID2, FID3, FID4, FID5, FID6, FID7, FID8: Fiducial; Fiducial_1mm_Mask2mm
H1, H2: MountingHole; MountingHole_8.4mm_M8
J1, J2, J3, J4: 2x18edgecon; 2x18-edge
J5: Conn_01x16; PinHeader_1x16_P2.54mm_Horizontal
J7: Conn_01x03; PinHeader_1x03_P2.54mm_Horizontal
J11, J12: Conn_02x40_Odd_Even; PinHeader_2x40_P1.27mm_Vertical
Q1, Q2, Q3, Q4, Q5, Q6, Q7, Q8, Q9, Q10, Q11, Q12, Q13, Q14, Q15, Q16, Q17, Q18, Q19, Q20, Q21, Q22, Q23, Q24, Q25, Q26, Q27, Q28, Q29, Q30, Q31, Q32, Q33, Q34, Q35, Q36, Q37, Q38, Q39, Q40, Q41, Q42, Q43, Q44, Q50, Q51, Q52, Q53, Q54, Q55, Q56, Q57, Q58, Q59, Q60, Q61, Q62, Q63, Q64: SSM6N15AFU; SOT-363_SC-70-6
R1, R2, R3, R4, R5, R6, R7, R8, R9, R10, R11, R12, R13, R15, R22, R24, R44, R45, R46, R47, R48, R49, R50, R51, R52, R53, R64, R65, R66, R67, R68, R69: 1K; R_0402_1005Metric
R101, R150, R151, R152, R153: 180; R_0402_1005Metric
R201, R250, R251, R252, R253: 390; R_0402_1005Metric

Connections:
+3V3: C1.1, C2.1, C3.1, C4.1, C5.1, C6.1, C7.1, C8.1, C9.1, C10.1, C11.1, C12.1, C20.1, J5.4, J11.3, J12.3, R1.1, R2.1, R3.1, R4.1, R5.1, R6.1, R7.1, R8.1, R9.1, R10.1, R11.1, R12.1, R13.1, R15.1, R22.1, R24.1, R44.1, R45.1, R46.1, R47.1, R48.1, R49.1, R50.1, R51.1, R52.1, R53.1, R64.1, R65.1, R66.1, R67.1, R68.1, R69.1
+5V: C13.1, C14.1, C15.1, C16.1, C17.1, C18.1, C19.1, J1.A2, J2.A2, J3.A2, J4.A2, J5.1, J7.1, R101.1, R150.1, R151.1, R152.1, R153.1
/A00_OUT_H: J11.17, Q57.5 (G2)
/A01_OUT_H: J12.42, Q14.5 (G2)
/A02_OUT_H: J12.44, Q13.5 (G2)
/A03_OUT_H: J11.31, Q63.5 (G2)
/A04_OUT_H: J11.29, Q62.5 (G2)
/A05_OUT_H: J12.25, Q21.5 (G2)
/A06_OUT_H: J12.23, Q20.5 (G2)
/A07_OUT_H: J11.27, Q61.5 (G2)
/A08_OUT_H: J11.23, Q60.5 (G2)
/A09_OUT_H: J12.22, Q19.5 (G2)
/A10_OUT_H: J12.24, Q18.5 (G2)
/A11_OUT_H: J12.26, Q17.5 (G2)
/A12_OUT_H: J11.46, Q10.5 (G2)
/A13_OUT_H: J11.21, Q59.5 (G2)
/A14_OUT_H: J12.34, Q16.5 (G2)
/A15_OUT_H: J11.9, Q54.5 (G2)
/A16_OUT_H: J11.11, Q55.5 (G2)
/A17_OUT_H: J11.32, Q11.5 (G2)
/AC_LO_IN_H: J11.70, Q8.6 (D1), R8.2
/AC_LO_OUT_H: J12.46, Q8.5 (G2)
/BBSY_IN_H: J12.29, Q22.6 (D1), R22.2
/BBSY_OUT_H: J12.27, Q22.5 (G2)
/BG4_IN_L: J11.65, Q53.6 (D1), R53.2
/BG4_OUT_L: J11.69, Q53.5 (G2)
/BG5_IN_L: J11.61, Q52.6 (D1), R52.2
/BG5_OUT_L: J11.63, Q52.5 (G2)
/BG6_IN_L: J11.57, Q51.6 (D1), R51.2
/BG6_OUT_L: J11.59, Q51.5 (G2)
/BG7_IN_L: J11.53, Q50.6 (D1), R50.2
/BG7_OUT_L: J11.55, Q50.5 (G2)
/BR4_OUT_H: J11.51, Q43.5 (G2)
/BR5_OUT_H: J11.47, Q42.5 (G2)
/BR6_OUT_H: J11.43, Q41.5 (G2)
/BR7_OUT_H: J11.41, Q40.5 (G2)
/BUS_A00_L: J3.H2, Q57.2 (G1), Q57.3 (D2)
/BUS_A01_L: J3.H1, Q14.2 (G1), Q14.3 (D2)
/BUS_A02_L: J3.F1, Q13.2 (G1), Q13.3 (D2)
/BUS_A03_L: J3.V2, Q63.2 (G1), Q63.3 (D2)
/BUS_A04_L: J3.U2, Q62.2 (G1), Q62.3 (D2)
/BUS_A05_L: J3.V1, Q21.2 (G1), Q21.3 (D2)
/BUS_A06_L: J3.U1, Q20.2 (G1), Q20.3 (D2)
/BUS_A07_L: J3.P2, Q61.2 (G1), Q61.3 (D2)
/BUS_A08_L: J3.N2, Q60.2 (G1), Q60.3 (D2)
/BUS_A09_L: J3.R1, Q19.2 (G1), Q19.3 (D2)
/BUS_A10_L: J3.P1, Q18.2 (G1), Q18.3 (D2)
/BUS_A11_L: J3.L1, Q17.2 (G1), Q17.3 (D2)
/BUS_A12_L: J3.C1, Q10.2 (G1), Q10.3 (D2)
/BUS_A13_L: J3.K2, Q59.2 (G1), Q59.3 (D2)
/BUS_A14_L: J3.K1, Q16.2 (G1), Q16.3 (D2)
/BUS_A15_L: J3.D2, Q54.2 (G1), Q54.3 (D2)
/BUS_A16_L: J3.E2, Q55.2 (G1), Q55.3 (D2)
/BUS_A17_L: J3.D1, Q11.2 (G1), Q11.3 (D2)
/BUS_AC_LO_L: J1.V1, Q8.2 (G1), Q8.3 (D2)
/BUS_BBSY_L: J4.D1, Q22.2 (G1), Q22.3 (D2)
/BUS_BG4_IN_H: J2.S2, Q53.2 (G1), R253.1
/BUS_BG4_OUT_H: J2.T2, Q53.3 (D2), R153.2
/BUS_BG5_IN_H: J2.P2, Q52.2 (G1), R252.1
/BUS_BG5_OUT_H: J2.R2, Q52.3 (D2), R152.2
/BUS_BG6_IN_H: J2.M2, Q51.2 (G1), R251.1
/BUS_BG6_OUT_H: J2.N2, Q51.3 (D2), R151.2
/BUS_BG7_IN_H: J2.K2, Q50.2 (G1), R250.1
/BUS_BG7_OUT_H: J2.L2, Q50.3 (D2), R150.2
/BUS_BR4_L: J2.H2, Q43.2 (G1), Q43.3 (D2)
/BUS_BR5_L: J2.F2, Q42.2 (G1), Q42.3 (D2)
/BUS_BR6_L: J2.E2, Q41.2 (G1), Q41.3 (D2)
/BUS_BR7_L: J2.D2, Q40.2 (G1), Q40.3 (D2)
/BUS_C0_L: J3.J2, Q58.2 (G1), Q58.3 (D2)
/BUS_C1_L: J3.F2, Q56.2 (G1), Q56.3 (D2)
/BUS_D00_L: J1.S2, Q36.2 (G1), Q36.3 (D2)
/BUS_D01_L: J1.R2, Q35.2 (G1), Q35.3 (D2)
/BUS_D02_L: J1.U2, Q38.2 (G1), Q38.3 (D2)
/BUS_D03_L: J1.T2, Q37.2 (G1), Q37.3 (D2)
/BUS_D04_L: J1.N2, Q33.2 (G1), Q33.3 (D2)
/BUS_D05_L: J1.P2, Q34.2 (G1), Q34.3 (D2)
/BUS_D06_L: J1.V2, Q39.2 (G1), Q39.3 (D2)
/BUS_D07_L: J1.M2, Q32.2 (G1), Q32.3 (D2)
/BUS_D08_L: J1.L2, Q31.2 (G1), Q31.3 (D2)
/BUS_D09_L: J1.K2, Q30.2 (G1), Q30.3 (D2)
/BUS_D10_L: J1.J2, Q29.2 (G1), Q29.3 (D2)
/BUS_D11_L: J1.H1, Q3.2 (G1), Q3.3 (D2)
/BUS_D12_L: J1.H2, Q28.2 (G1), Q28.3 (D2)
/BUS_D13_L: J1.F2, Q27.2 (G1), Q27.3 (D2)
/BUS_D14_L: J1.E2, Q26.2 (G1), Q26.3 (D2)
/BUS_D15_L: J1.D2, Q25.2 (G1), Q25.3 (D2)
/BUS_DC_LO_L: J1.N1, Q4.2 (G1), Q4.3 (D2)
/BUS_INIT_L: J2.L1, Q9.2 (G1), Q9.3 (D2)
/BUS_INTR_L: J4.M1, Q24.2 (G1), Q24.3 (D2)
/BUS_MSYN_L: J3.E1, Q12.2 (G1), Q12.3 (D2)
/BUS_NPG_IN_H: J1.A1, Q1.2 (G1), R201.1
/BUS_NPG_OUT_H: J1.B1, Q1.3 (D2), R101.2
/BUS_NPR_L: J4.J1, Q23.2 (G1), Q23.3 (D2)
/BUS_PA_L: J1.C1, Q2.2 (G1), Q2.3 (D2)
/BUS_PB_L: J1.S1, Q7.2 (G1), Q7.3 (D2)
/BUS_SACK_L: J4.T2, Q64.2 (G1), Q64.3 (D2)
/BUS_SSYN_L: J3.J1, Q15.2 (G1), Q15.3 (D2)
/C0_OUT_H: J11.19, Q58.5 (G2)
/C1_OUT_H: J11.13, Q56.5 (G2)
/D00_OUT_H: J12.58, Q36.5 (G2)
/D01_OUT_H: J12.62, Q35.5 (G2)
/D02_OUT_H: J12.54, Q38.5 (G2)
/D03_OUT_H: J12.56, Q37.5 (G2)
/D04_OUT_H: J12.66, Q33.5 (G2)
/D05_OUT_H: J12.64, Q34.5 (G2)
/D06_OUT_H: J12.52, Q39.5 (G2)
/D07_OUT_H: J12.77, Q32.5 (G2)
/D08_OUT_H: J12.75, Q31.5 (G2)
/D09_OUT_H: J12.73, Q30.5 (G2)
/D10_OUT_H: J12.69, Q29.5 (G2)
/D11_OUT_H: J12.79, Q3.5 (G2)
/D12_OUT_H: J12.67, Q28.5 (G2)
/D13_OUT_H: J12.65, Q27.5 (G2)
/D14_OUT_H: J12.59, Q26.5 (G2)
/D15_OUT_H: J12.55, Q25.5 (G2)
/DC_LO_IN_H: J12.76, Q4.6 (D1), R4.2
/DC_LO_OUT_H: J12.78, Q4.5 (G2)
/HALT_GRANT_H: J1.R1, Q6.2 (G1)
/HALT_RQST_L: J1.P1, Q5.2 (G1), Q5.3 (D2)
/HLTGR_IN_L: J12.72, Q6.6 (D1), R6.2
/HLTRQ_OUT_H: J12.74, Q5.5 (G2)
/INIT_IN_H: J11.64, Q9.6 (D1), R9.2
/INIT_OUT_H: J11.66, Q9.5 (G2)
/INTR_IN_H: J12.37, Q24.6 (D1), R24.2
/INTR_OUT_H: J12.35, Q24.5 (G2)
/IOB35LN7: J5.5, J12.39
/IOB35LN9: J5.8, J12.45
/IOB35LN11: J5.10, J12.49
/IOB35LP9: J5.7, J12.43
/IOB35LP11: J5.9, J12.47
/MSYN_IN_H: J11.20, Q12.6 (D1), R12.2
/MSYN_OUT_H: J11.22, Q12.5 (G2)
/MUXA: D1.2 (A), D5.2 (A), D8.2 (A), J11.18, R44.2
/MUXB: D2.2 (A), D6.2 (A), D9.2 (A), J11.26, R45.2
/MUXC: D3.2 (A), D7.2 (A), D10.2 (A), J11.28, R46.2
/MUXD: D4.2 (A), D11.2 (A), D27.2 (A), J11.30, R47.2
/MUXE: D12.2 (A), D23.2 (A), D28.2 (A), J11.48, R48.2
/MUXF: D13.2 (A), D22.2 (A), D29.2 (A), J11.38, R49.2
/MUXH: D14.2 (A), D21.2 (A), D30.2 (A), J11.36, R65.2
/MUXJ: D15.2 (A), D20.2 (A), D31.2 (A), J11.50, R66.2
/MUXK: D19.2 (A), D35.2 (A), D42.2 (A), J11.52, R67.2
/MUXL: D18.2 (A), D36.2 (A), D43.2 (A), J11.56, R68.2
/MUXM: D17.2 (A), D37.2 (A), D44.2 (A), J11.58, R69.2
/MUXN: D16.2 (A), D34.2 (A), D38.2 (A), J11.60, R3.2
/MUXP: D24.2 (A), D33.2 (A), D39.2 (A), J11.62, R10.2
/MUXR: D25.2 (A), D32.2 (A), D40.2 (A), J11.7, R11.2
/MUXS: D26.2 (A), D41.2 (A), J11.16, R13.2
/NPG_IN_L: J12.57, Q1.6 (D1), R1.2
/NPG_OUT_L: J12.53, Q1.5 (G2)
/NPR_OUT_H: J12.33, Q23.5 (G2)
/PA_OUT_H: J12.63, Q2.5 (G2)
/PB_OUT_H: J12.48, Q7.5 (G2)
/RSEL1_H: J12.68, Q6.5 (G2)
/RSEL1_L: Q2.1 (S1), Q3.1 (S1), Q5.1 (S1), Q6.3 (D2), Q7.1 (S1), Q25.1 (S1), Q26.1 (S1), Q27.1 (S1), Q28.1 (S1), Q29.1 (S1), Q30.1 (S1), Q31.1 (S1), Q32.1 (S1), Q33.1 (S1), Q34.1 (S1), Q35.1 (S1), R2.2
/RSEL2_H: J12.28, Q44.5 (G2)
/RSEL2_L: Q10.1 (S1), Q11.1 (S1), Q13.1 (S1), Q36.1 (S1), Q37.1 (S1), Q38.1 (S1), Q39.1 (S1), Q40.1 (S1), Q41.1 (S1), Q42.1 (S1), Q43.1 (S1), Q44.3 (D2), Q54.1 (S1), Q55.1 (S1), Q56.1 (S1), R7.2
/RSEL3_H: J12.32, Q44.2 (G1)
/RSEL3_L: Q14.1 (S1), Q16.1 (S1), Q17.1 (S1), Q18.1 (S1), Q19.1 (S1), Q20.1 (S1), Q21.1 (S1), Q23.1 (S1), Q44.6 (D1), Q57.1 (S1), Q58.1 (S1), Q59.1 (S1), Q60.1 (S1), Q61.1 (S1), Q62.1 (S1), Q63.1 (S1), R5.2
/SACK_IN_H: J11.33, Q64.6 (D1), R64.2
/SACK_OUT_H: J11.37, Q64.5 (G2)
/SSYN_IN_H: J12.36, Q15.6 (D1), R15.2
/SSYN_OUT_H: J12.38, Q15.5 (G2)
/V5ZYNQ: J5.2, J7.2, J11.1, J12.1
/VDDIO35: J5.11, J12.51
GND: C1.2, C2.2, C3.2, C4.2, C5.2, C6.2, C7.2, C8.2, C9.2, C10.2, C11.2, C12.2, C13.2, C14.2, C15.2, C16.2, C17.2, C18.2, C19.2, C20.2, J1.C2, J1.T1, J2.C2, J2.T1, J3.C2, J3.T1, J4.C2, J4.T1, J5.6, J5.16, J7.3, J11.2, J11.4, J11.24, J11.25, J11.34, J11.35, J11.44, J11.54, J11.67, J11.68, J12.2, J12.4, J12.20, J12.21, J12.30, J12.31, J12.40, J12.41, J12.50, J12.60, J12.61, J12.70, J12.71, J12.80, Q1.1 (S1), Q1.4 (S2), Q2.4 (S2), Q3.4 (S2), Q4.1 (S1), Q4.4 (S2), Q5.4 (S2), Q6.1 (S1), Q6.4 (S2), Q7.4 (S2), Q8.1 (S1), Q8.4 (S2), Q9.1 (S1), Q9.4 (S2), Q10.4 (S2), Q11.4 (S2), Q12.1 (S1), Q12.4 (S2), Q13.4 (S2), Q14.4 (S2), Q15.1 (S1), Q15.4 (S2), Q16.4 (S2), Q17.4 (S2), Q18.4 (S2), Q19.4 (S2), Q20.4 (S2), Q21.4 (S2), Q22.1 (S1), Q22.4 (S2), Q23.4 (S2), Q24.1 (S1), Q24.4 (S2), Q25.4 (S2), Q26.4 (S2), Q27.4 (S2), Q28.4 (S2), Q29.4 (S2), Q30.4 (S2), Q31.4 (S2), Q32.4 (S2), Q33.4 (S2), Q34.4 (S2), Q35.4 (S2), Q36.4 (S2), Q37.4 (S2), Q38.4 (S2), Q39.4 (S2), Q40.4 (S2), Q41.4 (S2), Q42.4 (S2), Q43.4 (S2), Q44.1 (S1), Q44.4 (S2), Q50.1 (S1), Q50.4 (S2), Q51.1 (S1), Q51.4 (S2), Q52.1 (S1), Q52.4 (S2), Q53.1 (S1), Q53.4 (S2), Q54.4 (S2), Q55.4 (S2), Q56.4 (S2), Q57.4 (S2), Q58.4 (S2), Q59.4 (S2), Q60.4 (S2), Q61.4 (S2), Q62.4 (S2), Q63.4 (S2), Q64.1 (S1), Q64.4 (S2), R201.2, R250.2, R251.2, R252.2, R253.2
unnamed: D1.1 (K), Q2.6 (D1)
unnamed: D2.1 (K), Q3.6 (D1)
unnamed: D3.1 (K), Q5.6 (D1)
unnamed: D4.1 (K), Q7.6 (D1)
unnamed: D5.1 (K), Q10.6 (D1)
unnamed: D6.1 (K), Q11.6 (D1)
unnamed: D7.1 (K), Q13.6 (D1)
unnamed: D8.1 (K), Q14.6 (D1)
unnamed: D9.1 (K), Q16.6 (D1)
unnamed: D10.1 (K), Q17.6 (D1)
unnamed: D11.1 (K), Q18.6 (D1)
unnamed: D12.1 (K), Q19.6 (D1)
unnamed: D13.1 (K), Q20.6 (D1)
unnamed: D14.1 (K), Q21.6 (D1)
unnamed: D15.1 (K), Q23.6 (D1)
unnamed: D16.1 (K), Q32.6 (D1)
unnamed: D17.1 (K), Q31.6 (D1)
unnamed: D18.1 (K), Q30.6 (D1)
unnamed: D19.1 (K), Q29.6 (D1)
unnamed: D20.1 (K), Q28.6 (D1)
unnamed: D21.1 (K), Q27.6 (D1)
unnamed: D22.1 (K), Q26.6 (D1)
unnamed: D23.1 (K), Q25.6 (D1)
unnamed: D24.1 (K), Q33.6 (D1)
unnamed: D25.1 (K), Q34.6 (D1)
unnamed: D26.1 (K), Q35.6 (D1)
unnamed: D27.1 (K), Q36.6 (D1)
unnamed: D28.1 (K), Q37.6 (D1)
unnamed: D29.1 (K), Q38.6 (D1)
unnamed: D30.1 (K), Q39.6 (D1)
unnamed: D31.1 (K), Q40.6 (D1)
unnamed: D32.1 (K), Q56.6 (D1)
unnamed: D33.1 (K), Q55.6 (D1)
unnamed: D34.1 (K), Q54.6 (D1)
unnamed: D35.1 (K), Q57.6 (D1)
unnamed: D36.1 (K), Q58.6 (D1)
unnamed: D37.1 (K), Q59.6 (D1)
unnamed: D38.1 (K), Q60.6 (D1)
unnamed: D39.1 (K), Q61.6 (D1)
unnamed: D40.1 (K), Q62.6 (D1)
unnamed: D41.1 (K), Q63.6 (D1)
unnamed: D42.1 (K), Q41.6 (D1)
unnamed: D43.1 (K), Q42.6 (D1)
unnamed: D44.1 (K), Q43.6 (D1)

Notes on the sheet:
led-red
led-grn
led-blu

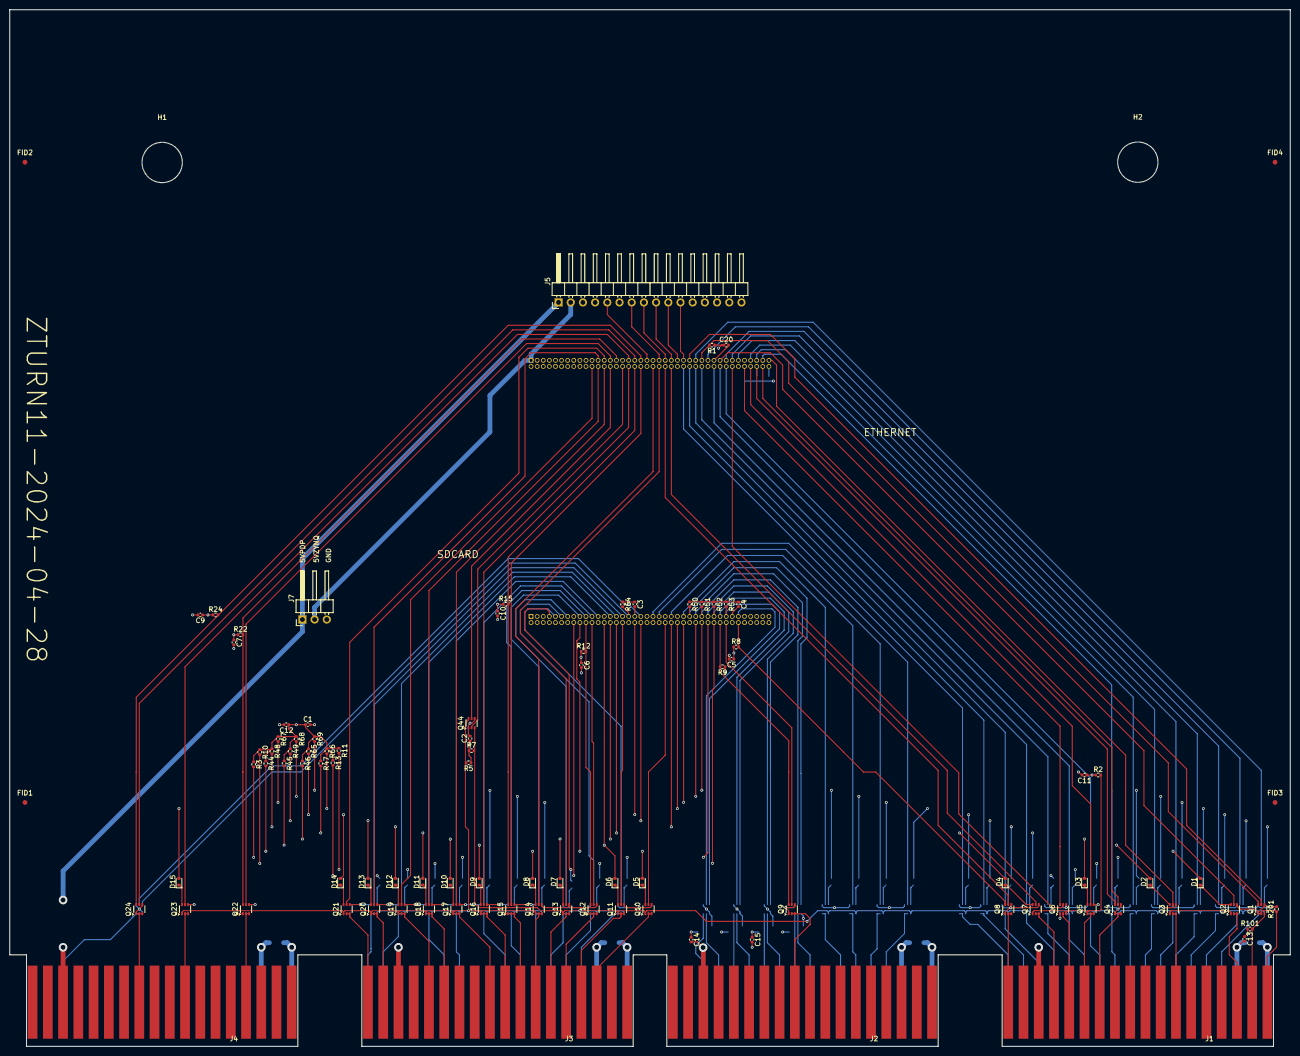
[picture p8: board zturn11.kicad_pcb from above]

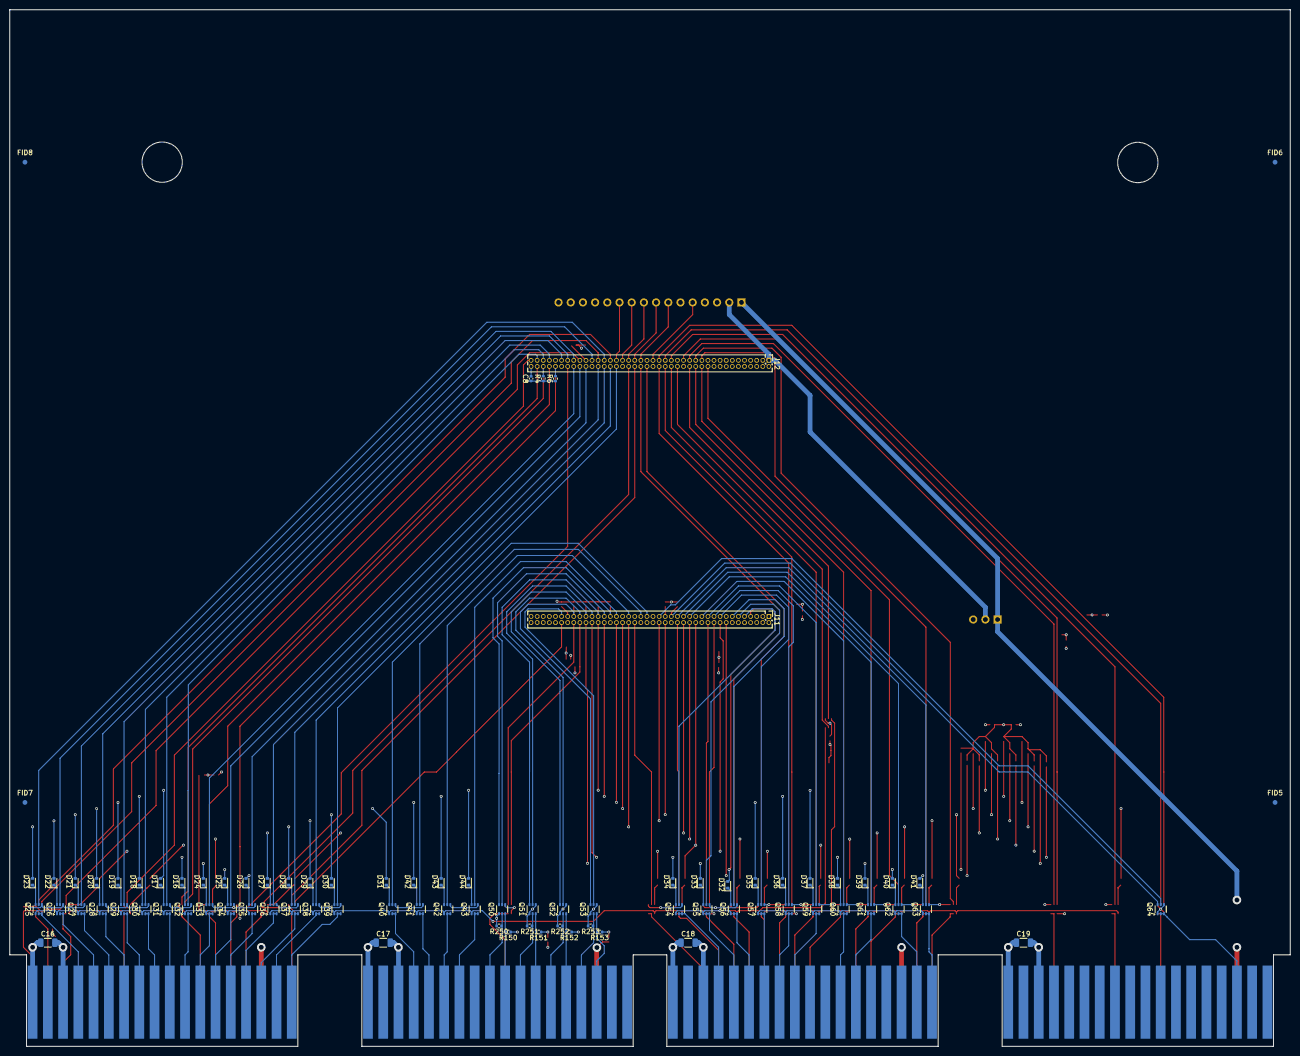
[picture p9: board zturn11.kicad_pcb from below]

Board: 4 copper layers, 266.7 x 215.9 mm, 183 parts (84 on the bottom side), 209 nets.

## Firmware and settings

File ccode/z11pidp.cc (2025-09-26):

//    Copyright (C) Mike Rieker, Beverly, MA USA
//    www.outerworldapps.com
//
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
//    EXPECT it to FAIL when someone's HeALTh or PROpeRTy is at RISk.
//
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
//    http://www.gnu.org/licenses/gpl-2.0.html

// Run on a RasPI plugged into PiDP-11 panel
//   ./z11pidp client
// Uses UDP to communicate with ZTurn to control/monitor the PDP
// Must be running the pidp server on the ZTurn:
//   ./z11pidp server

// PAR ERR  - last exam got a parity error
// ADDR ERR - last dep or exam got an address error
// RUN      - processor executing instructions
// USER     - PS indicates USER mode
// KERNEL   - PS indicates KERNEL mode
// ADDR 16  - mmu is turned off
//      18  - mmu is turned on

// ADDRESS - running: latest bus cycle physical address
//           halted:  latest ldaddr/exam/deposit address
//                    CON PHYS: physical address
//               USER,KERNEL I: virtual address
// CONS PHY - load address will load a physical address
// USER I   - load address will load a user virt address
// KERNEL I - load address will load a kernel virt addr
// PROG PHY - address lights show physical address (push knob to activate)

// DATA
//    DATA PATHS - running: shows R0
//               - halted:  shows exam/deposit data
//   DISPLAY REG - shows 777570 light register

// LDAD,EXAM,DEP - usual function
// CONT,ENAB/HALT,START - usual fuction
// SINGLE INST/CYCLE - doesn't do anything, always single inst mode
// SR<21> ON - enables SR<15:00> to write 777570 switch register
//       OFF - use value from GUI switches or z11ctrl ky_switches
//             for 777570 switch register

#include <arpa/inet.h>
#include <errno.h>
#include <fcntl.h>
#include <netdb.h>
#include <pthread.h>
#include <signal.h>
#include <stdio.h>
#include <stdlib.h>
#include <string.h>
#include <sys/mman.h>
#include <sys/wait.h>
#include <time.h>
#include <unistd.h>

#include "futex.h"
#include "z11defs.h"
#include "z11util.h"

// gpio pins

                    // LED0 LED1 LED2 LED3 LED4 LED5 ROW0 ROW1 ROW2
#define COL00   26  //  A00  A12 AD22  D00  D12      SR00 SR12 TEST
#define COL01   27  //  A01  A13 AD18  D01  D13      SR01 SR13 LDAD
#define COL02    4  //  A02  A14 AD16  D02  D14      SR02 SR14 EXAM
#define COL03    5  //  A03  A15 DATA  D03  D15      SR03 SR15 DEP
#define COL04    6  //  A04  A16 KERN  D04 PARL      SR04 SR16 CONT
#define COL05    7  //  A05  A17 SUPR  D05 PARH      SR05 SR17 HALT
#define COL06    8  //  A06  A18 USER  D06 ADUD ADUI SR06 SR18 SINS
#define COL07    9  //  A07  A19 MAST  D07 ADSD ADSI SR07 SR19 STRT
#define COL08   10  //  A08  A20 PAUS  D08 ADKD ADKI SR08 SR20 ADRA
#define COL09   11  //  A09  A21 RUN   D09 ADCP ADPP SR09 SR21 ADRB
#define COL10   12  //  A10      AERR  D10 DADP DAMU SR10 ADSW DARA
#define COL11   13  //  A11      PERR  D11 DABR DADR SR11 DASW DARB

#define LED0 20
#define LED1 21
#define LED2 22
#define LED3 23
#define LED4 24
#define LED5 25

#define ROW0 16
#define ROW1 17
#define ROW2 18

#define L0_A1100 07777
#define L1_A2112 01777
#define L2_AD18  00002
#define L2_AD16  00004
#define L2_KERN  00020
#define L2_USER  00100
#define L2_RUN   01000
#define L2_AERR  02000
#define L2_PERR  04000
#define L3_D1100 07777
#define L4_D1512 00017
#define L4_ADCP  01000
#define L4_DADP  02000
#define L5_ADUI  00100
#define L5_ADKI  00400
#define L5_ADPP  01000
#define L5_DADR  04000

#define R0_SR1100 07777
#define R1_SR2112 01777
#define R1_ADSW   02000
#define R1_DASW   04000
#define R2_TEST_  00001
#define R2_LDAD   00002
#define R2_EXAM   00004
#define R2_DEP    00010
#define R2_CONT   00020
#define R2_HALT   00040
#define R2_STRT   00200
#define R2_ADRA   00400
#define R2_ADRB   01000
#define R2_DARA   02000
#define R2_DARB   04000

#define BB(m) (m & - m)

#define IGO 1

#define GPIO_FSEL0 0
#define GPIO_SET0 (0x1C/4) //  7
#define GPIO_CLR0 (0x28/4) // 10
#define GPIO_LEV0 (0x34/4) // 13

#define GPIO_PUD     (0x94/4) // 37
#define GPIO_PUDCLK0 (0x98/4) // 38

#define GPIO_PUD_OFF  0
#define GPIO_PUD_DOWN 1
#define GPIO_PUD_UP   2

#define PIDPUDPPORT 5826

enum AddrSw {
    CONSPHY = 0,
    USERINS = 1,
    KERNINS = 2,
    ADSWMAX = 3
};

enum DataSw {
    DATAPTH = 0,
    DISPREG = 1,
    DASWMAX = 2
};

struct PiDPUDPPkt {
    uint64_t seq;
    uint16_t leds[6];
    uint16_t rows[3];
};

static uint32_t const colbits[] = {
    1U << COL00, 1U << COL01, 1U << COL02, 1U << COL03, 1U << COL04, 1U << COL05,
    1U << COL06, 1U << COL07, 1U << COL08, 1U << COL09, 1U << COL10, 1U << COL11 };

static uint32_t const colbitsall =
    (1U << COL00) | (1U << COL01) | (1U << COL02) | (1U << COL03) | (1U << COL04) | (1U << COL05) |
    (1U << COL06) | (1U << COL07) | (1U << COL08) | (1U << COL09) | (1U << COL10) | (1U << COL11);

static uint32_t const ledbits[] = { 1U << LED0, 1U << LED1, 1U << LED2, 1U << LED3, 1U << LED4, 1U << LED5 };
static uint32_t const rowbits[] = { 1U << ROW0, 1U << ROW1, 1U << ROW2 };

static void client (int argc, char **argv);
static void *gpiothd (void *dummy);
static void writeleds (uint32_t volatile *gpiopage, uint16_t *leds);

static void server ();
static uint32_t didldaddr (uint32_t loadedaddr, AddrSw addrsw, uint16_t *leds2);

static int openclientsocket (struct sockaddr_in *cliaddr);
static int openserversocket (struct sockaddr_in *svraddr);
static void getserveripaddr (struct sockaddr_in *cliaddr, char const *server);

int main (int argc, char **argv)
{
    setlinebuf (stdout);

    if ((argc >= 2) && (strcasecmp (argv[1], "client") == 0)) client (argc - 1, argv + 1);
    if ((argc == 2) && (strcasecmp (argv[1], "server") == 0)) server ();
    return 0;
}

// run on raspi plugged into pidp-11 panel
//  pidp client [ -test | <serveraddr> ]
static int clientseq;
static uint16_t ledrows[6];
static uint16_t swtrows[3];
static void client (int argc, char **argv)
{
    char const *server = NULL;
    for (int i = 0; ++ i < argc;) {
        if (argv[i][0] == '-') {
            fprintf (stderr, "unknown option %s\n", argv[i]);
            ABORT ();
        }
        if (server != NULL) {
            fprintf (stderr, "unknown argument %s\n", argv[i]);
            ABORT ();
        }
        server = argv[i];
    }
    if (server == NULL) {
        fprintf (stderr, "missing server address\n");
        ABORT ();
    }

    // set up sequence number gt anything previously used
    PiDPUDPPkt pidpmsg;
    memset (&pidpmsg, 0, sizeof pidpmsg);
    struct timespec nowts;
    if (clock_gettime (CLOCK_REALTIME, &nowts) < 0) ABORT ();
    uint64_t sendseq = nowts.tv_sec * 1000000000ULL + nowts.tv_nsec;

    // open socket to communicate to server with
    struct sockaddr_in cliaddr;
    int udpfd = openclientsocket (&cliaddr);

    // set up to send to GPIOUDPPORT on server
    struct sockaddr_in svraddr;
    memset (&svraddr, 0, sizeof svraddr);
    svraddr.sin_family = AF_INET;
    svraddr.sin_port = htons (PIDPUDPPORT);
    getserveripaddr (&svraddr, server);

    // start thread to update leds and read switches
    pthread_t thid;
    if (pthread_create (&thid, NULL, gpiothd, NULL) != 0) ABORT ();

    int lastseq = 0;

    while (true) {

        // wait for an LED/switch update cycle to complete
        while (clientseq == lastseq) {
            if (futex (&clientseq, FUTEX_WAIT, lastseq, NULL, NULL, 0) < 0) {
                if (errno != EAGAIN) ABORT ();
            }
        }
        lastseq = clientseq;

        // send switches to server, trigger receiving leds
        pidpmsg.seq = ++ sendseq;
        memcpy (pidpmsg.rows, swtrows, sizeof pidpmsg.rows);
        int rc = sendto (udpfd, &pidpmsg, sizeof pidpmsg, 0, (struct sockaddr *) &svraddr, sizeof svraddr);
        if (rc != (int) sizeof pidpmsg) {
            if (rc < 0) {
                fprintf (stderr, "error sending udp packet: %m\n");
            } else {
                fprintf (stderr, "only sent %d of %d bytes over udp\n", rc, (int) sizeof pidpmsg);
            }
            ABORT ();
        }

        // receive leds from server
        do {
            struct sockaddr_in cliaddr;
            socklen_t addrlen = sizeof cliaddr;
            int rc = recvfrom (udpfd, &pidpmsg, sizeof pidpmsg, 0, (struct sockaddr *) &cliaddr, &addrlen);
            if (rc != (int) sizeof pidpmsg) {
                if (rc < 0) {
                    if (errno == EAGAIN) break;
                    fprintf (stderr, "error receiving udp packet: %m\n");
                } else {
                    fprintf (stderr, "only received %d of %d bytes over udp\n", rc, (int) sizeof pidpmsg);
                }
                ABORT ();
            }
        } while (pidpmsg.seq < sendseq);
        memcpy (ledrows, pidpmsg.leds, sizeof ledrows);
    }
}

// display leds and sense switches at hopefully a constant rate
static void *gpiothd (void *dummy)
{
    // access gpio page to access leds and switches
    int gpiofd = open ("/dev/gpiomem", O_RDWR);
    if (gpiofd < 0) {
        fprintf (stderr, "error opening /dev/gpiomem: %m\n");
        ABORT ();
    }
    void *gpioptr = mmap (NULL, 4096, PROT_READ | PROT_WRITE, MAP_SHARED, gpiofd, 0);
    if (gpioptr == MAP_FAILED) {
        fprintf (stderr, "error mmapping /dev/gpiomem: %m\n");
        ABORT ();
    }
    uint32_t volatile *gpiopage = (uint32_t volatile *) gpioptr;

    // configure:
    //  columns with pullup
    //  rows,leds,columns all set to inputs for now
    gpiopage[GPIO_FSEL0+0] = 0;
    gpiopage[GPIO_FSEL0+1] = 0;
    gpiopage[GPIO_FSEL0+2] = 0;

    for (int g = 4; g <= 27; g ++) {
        gpiopage[GPIO_PUD] = (colbitsall & (1U << g)) ? GPIO_PUD_UP : GPIO_PUD_OFF;
        usleep (20);
        gpiopage[GPIO_PUDCLK0] = 1U << g;
        usleep (20);
        gpiopage[GPIO_PUD] = 0;
        gpiopage[GPIO_PUDCLK0] = 0;
    }

    while (true) {

        // write leds - leds,cols = outputs; rows = inputs (hi-Z)
        writeleds (gpiopage, ledrows);

        // read switches -
        // - led rows = inputs (hi-Z)
        // - active switch row: output low
        //              others: input (hi-Z)
        // - cols = inputs with pullups
        gpiopage[GPIO_FSEL0+0] = 0;
        gpiopage[GPIO_FSEL0+1] = 0;
        gpiopage[GPIO_FSEL0+2] = 0;
        gpiopage[GPIO_CLR0] = -1;

        for (int r = 0; r <= 2; r ++) {
            ASSERT ((ROW0 >= 10) && (ROW2 <= 19) && (ROW1 == ROW0 + 1) && (ROW2 == ROW0 + 2));
            gpiopage[GPIO_FSEL0+1] = IGO << ((r + ROW0 - 10) * 3);
            usleep (1);
            uint32_t gpin = ~ gpiopage[GPIO_LEV0];  // active low inputs
            uint16_t row  = 0;
            for (int c = 0; c <= 11; c ++) {
                if (gpin & colbits[c]) row |= 1U << c;
            }
            swtrows[r] = row;
        }
        gpiopage[GPIO_FSEL0+1] = 0;

        // trigger a transmit/receive cycle
        clientseq ++;
        if (futex (&clientseq, FUTEX_WAKE, 1000000000, NULL, NULL, 0) < 0) ABORT ();
    }
}

static void writeleds (uint32_t volatile *gpiopage, uint16_t *leds)
{
    gpiopage[GPIO_FSEL0+0] = IGO * 01111110000; // COL07..COL02
    gpiopage[GPIO_FSEL0+1] = IGO * 00000001111; // COL11..COL08
    gpiopage[GPIO_FSEL0+2] = IGO * 00011111111; // COL01..COL00,LED5..LED0

    for (int r = 0; r <= 5; r ++) {

        // compute row of leds
        // line for selected led row is high, other led rows low
        // column bit is active low
        uint32_t gpout = ledbits[r];            // set LEDn bit to activate the led row
        uint16_t ledn = ~ leds[r];              // led bits for the row
        for (int c = 0; c <= 11; c ++) {
            if (ledn & 1) gpout |= colbits[c];  // active low column bit
            ledn >>= 1;
        }
        gpiopage[GPIO_CLR0] = ~ gpout;
        gpiopage[GPIO_SET0] =   gpout;

        // leave led row on for 3.333333mS
        int const ledonns = 3333333;
        struct timespec ts;
        if (clock_gettime (CLOCK_MONOTONIC, &ts) < 0) ABORT ();
        ts.tv_nsec = ledonns - ts.tv_nsec % ledonns;
        ts.tv_sec  = 0;
        if (nanosleep (&ts, NULL) < 0) ABORT ();
    }
}

//////////////
//  SERVER  //
//////////////

// runs on zturn
//  receives switches from client then updates fpga registers
//  reads fpga registers then sends led states to client
static void server ()
{
    struct sockaddr_in svraddr;
    int udpfd = openserversocket (&svraddr);

    // access fpga state page
    z11page = new Z11Page ();
    uint32_t volatile *pdpat = z11page->findev ("11", NULL, NULL, false);
    uint32_t volatile *kyat  = z11page->findev ("KY", NULL, NULL, false);

    AddrSw   addrsw     = CONSPHY;  // load address type
    bool     lastdep    = false;    // increment address before deposit
    bool     lastexam   = false;    // increment address before examine
    bool     progphy    = false;    // showing physical address
    DataSw   datasw     = DATAPTH;  // data display select
    int      bootpid    = -1;       // boot process id
    int      ignorerot  = 0;        // ignore rotary switches for this many cycles
    int      oldrown    = 0;        // debounce switch index
    uint16_t leds2      = 0;        // status leds
    uint16_t memorydata = 0;        // data display leds
    uint32_t ldphysaddr = 0;        // equivalent physical address
    uint32_t loadedaddr = 0;        // address display leds
    uint32_t testled    = 0;        // which led is being tested with lamp test switch
    uint64_t recvseq    = 0;        // filter out duplicate udp receives

#define NOLDROWS 4                  // number of old readings to save for debouncing
    uint16_t oldrow1s[NOLDROWS], oldrow2s[NOLDROWS];
    memset (oldrow1s, 0, sizeof oldrow1s);
    memset (oldrow2s, 0, sizeof oldrow2s);

    while (true) {

        // receive switches from client
        PiDPUDPPkt pidpmsg;
        struct sockaddr_in cliaddr;
        do {
            socklen_t addrlen = sizeof cliaddr;
            int rc = recvfrom (udpfd, &pidpmsg, sizeof pidpmsg, 0, (struct sockaddr *) &cliaddr, &addrlen);
            if (rc != (int) sizeof pidpmsg) {
                if (rc < 0) {
                    fprintf (stderr, "error receiving udp packet: %m\n");
                } else {
                    fprintf (stderr, "only received %d of %d bytes over udp\n", rc, (int) sizeof pidpmsg);
                }
                ABORT ();
            }
        } while (pidpmsg.seq <= recvseq);
        recvseq = pidpmsg.seq;

        // get switch register
        uint32_t sr = (((pidpmsg.rows[1] & R1_SR2112) / BB(R1_SR2112)) << 12) |
                       ((pidpmsg.rows[0] & R0_SR1100) / BB(R0_SR1100));

        // debounce momentary switches and detect positive edges
        oldrow1s[oldrown] = pidpmsg.rows[1];
        oldrow2s[oldrown] = pidpmsg.rows[2];
        if (++ oldrown == NOLDROWS) oldrown = 0;
        uint16_t posedge1 = ~ oldrow1s[oldrown];
        uint16_t posedge2 = ~ oldrow2s[oldrown];
        for (int j = oldrown; (j = (j + 1) % NOLDROWS) != oldrown;) {
            posedge1 &= oldrow1s[j];
            posedge2 &= oldrow2s[j];
        }

        // posedge on ADSW toggles progphy mode
        if (posedge1 & R1_ADSW) progphy = ! progphy;

        // posedge on DASW spawns boot script
        if (posedge1 & R1_DASW) {
            char *env = getenv ("bootscript");
            if (env == NULL) {
                fprintf (stderr, "bootscript envar not defined\n");
            } else {
                if ((bootpid > 0) && (waitpid (bootpid, NULL, WNOHANG) == 0)) {
                    if (kill (bootpid, SIGKILL) >= 0) waitpid (bootpid, NULL, 0);
                }
                bootpid = fork ();
                if (bootpid < 0) {
                    fprintf (stderr, "error forking boot process: %m\n");
                } else if (bootpid == 0) {
                    char swregstr[14], ldadrstr[14];
                    sprintf (swregstr, "%u", sr);
                    sprintf (ldadrstr, "%u", loadedaddr);
                    char pidp[] = "pidp";
                    char *args[] = { env, swregstr, ldadrstr, pidp, NULL };
                    execvp (env, args);
                    fprintf (stderr, "error execing boot script %s: %m\n", env);
                    exit (255);
                }
            }
        }

        if (ignorerot == 0) {

            // pos edge on ADRA means increment addrsw; ADRB means decrement
            // get sequences like AAB, AAAABAABA when rotating left
            // get sequences like BAA, BBAABBAAB when rotating right
            if (posedge2 & R2_ADRA) addrsw = (AddrSw) ((addrsw + 1) % ADSWMAX);
            if (posedge2 & R2_ADRB) addrsw = (AddrSw) ((addrsw - 1) % ADSWMAX);

            // likewise with DARA, DARB
            if (posedge2 & R2_DARA) datasw = (DataSw) ((datasw + 1) % DASWMAX);
            if (posedge2 & R2_DARB) datasw = (DataSw) ((datasw - 1) % DASWMAX);
        }

        // ignore any redundant edges
        if (posedge2 & (R2_ADRA | R2_ADRB | R2_DARA | R2_DARB)) ignorerot = NOLDROWS * 2;
        else if (ignorerot != 0) -- ignorerot;

        // make sure some use of snapregs() or dma won't messing with KY registers whilst we are in here
        z11page->dmalock ();

        // set the 777570 register switches if SR<21> is set
        if (sr & 010000000) {
            ZWR(kyat[1], (ZRD(kyat[1]) & ~ KY_SWITCHES) | (sr * BB(KY_SWITCHES) & KY_SWITCHES));
            ZWR(kyat[2], (ZRD(kyat[2]) & ~ KY2_SR1716) | ((sr >> 16) * BB(KY2_SR1716) & KY2_SR1716));
        }

        // if HALT switch set, set the KY_HALTREQ line
        if (pidpmsg.rows[2] & R2_HALT) {
            ZWR(kyat[2], ZRD(kyat[2]) | KY2_HALTREQ);
        }

        // momentaries work only when processor halted
        uint32_t fpgamode = (ZRD(pdpat[Z_RA]) & a_fpgamode) / BB(a_fpgamode);
        bool running = ! (ZRD(kyat[2]) & KY2_HALTED);
        if (running) {

            // running, display address bus and data bus
            // also clear any loadaddress/examine/deposit context
            loadedaddr = (ZRD(pdpat[Z_RK]) & k_lataddr) / BB(k_lataddr);
            memorydata = (ZRD(pdpat[Z_RL]) & l_latdata) / BB(l_latdata);
            ldphysaddr = loadedaddr;
            if (fpgamode == FM_REAL) {
                uint16_t r0;
                if (z11page->snapregs (0777700, 0, &r0) > 0) memorydata = r0;
            }
            leds2   &= ~ (L2_AERR | L2_PERR);
            leds2   |=    L2_RUN;
            lastdep  = false;
            lastexam = false;
        } else {

            // if newly halted, get PC and R0 for address and data
            if (leds2 & L2_RUN) {
                leds2 &= ~ L2_RUN;
                uint16_t pc, ps, r0;
                addrsw = CONSPHY;
                if (z11page->dmareadlocked (0777776, &ps) == 0) {
                    if ((ps & 0140000) == 0000000) addrsw = KERNINS;
                    if ((ps & 0140000) == 0140000) addrsw = USERINS;
                }
                loadedaddr = (z11page->dmareadlocked (0777707, &pc) == 0) ? pc : 0777777;
                memorydata = (z11page->dmareadlocked (0777700, &r0) == 0) ? r0 : 0177777;
                ldphysaddr = (loadedaddr == 0777777) ? 0777777 : didldaddr (loadedaddr, addrsw, &leds2);
            }

            // load address, examine, deposit
            if (posedge2 & R2_LDAD) {
                loadedaddr = sr & 0777777;
                if ((loadedaddr < 0777700) || (loadedaddr > 0777717)) loadedaddr &= -2;
                ldphysaddr = didldaddr (loadedaddr, addrsw, &leds2);
                memorydata = 0;
                lastdep  = false;
                lastexam = false;
            }
            if (posedge2 & R2_EXAM) {
                uint32_t addrinc = ((ldphysaddr < 0777700) || (ldphysaddr > 0777717)) ? 2 : 1;
                if (lastexam) loadedaddr = (loadedaddr + addrinc) & 0777777;
                ldphysaddr = didldaddr (loadedaddr, addrsw, &leds2);
                if (! (leds2 & L2_AERR)) {
                    uint32_t rc = z11page->dmareadlocked (ldphysaddr, &memorydata);
                    if (rc & KY3_DMATIMO) leds2 |= L2_AERR;
                    if (rc & KY3_DMAPERR) leds2 |= L2_PERR;
                }
                lastdep  = false;
                lastexam = true;
            }
            if (posedge2 & R2_DEP) {
                memorydata = sr;
                uint32_t addrinc = ((ldphysaddr < 0777700) || (ldphysaddr > 0777717)) ? 2 : 1;
                if (lastdep) loadedaddr = (loadedaddr + addrinc) & 0777777;
                ldphysaddr = didldaddr (loadedaddr, addrsw, &leds2);
                if (! (leds2 & L2_AERR)) {
                    if (! z11page->dmawritelocked (ldphysaddr, memorydata)) leds2 |= L2_AERR;
                }
                lastdep  = true;
                lastexam = false;
            }

            // posedge CONT : single step or resume processing
            if (posedge2 & R2_CONT) {
                if (pidpmsg.rows[2] & R2_HALT) {
                    // halt switch on - step single instruction
                    z11page->dmaunlk ();
                    z11page->stepreq ();
                    for (int i = 0; ZRD(kyat[2]) & KY2_STEPREQ; i ++) {
                        if (i > 1000) break;
                    }
                    z11page->dmalock ();
                    uint16_t pc, r0;
                    loadedaddr = (z11page->dmareadlocked (0777707, &pc) == 0) ? pc : 0177777;
                    memorydata = (z11page->dmareadlocked (0777700, &r0) == 0) ? r0 : 0177777;
                } else {
                    // halt switch off - clear halt request line
                    ZWR(kyat[2], ZRD(kyat[2]) & ~ KY2_HALTREQ);
                }
                leds2   &= ~ (L2_AERR | L2_PERR);
                lastdep  = false;
                lastexam = false;
            }
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

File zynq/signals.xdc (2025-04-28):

set_property PACKAGE_PIN Y7 [get_ports {a_out_h_0[0]}]
set_property IOSTANDARD LVCMOS33 [get_ports {a_out_h_0[0]}]
set_property PACKAGE_PIN K19 [get_ports {a_out_h_0[1]}]
set_property IOSTANDARD LVCMOS33 [get_ports {a_out_h_0[1]}]
set_property PACKAGE_PIN J19 [get_ports {a_out_h_0[2]}]
set_property IOSTANDARD LVCMOS33 [get_ports {a_out_h_0[2]}]
set_property PACKAGE_PIN V12 [get_ports {a_out_h_0[3]}]
set_property IOSTANDARD LVCMOS33 [get_ports {a_out_h_0[3]}]
set_property PACKAGE_PIN U12 [get_ports {a_out_h_0[4]}]
set_property IOSTANDARD LVCMOS33 [get_ports {a_out_h_0[4]}]
set_property PACKAGE_PIN B20 [get_ports {a_out_h_0[5]}]
set_property IOSTANDARD LVCMOS33 [get_ports {a_out_h_0[5]}]
set_property PACKAGE_PIN C20 [get_ports {a_out_h_0[6]}]
set_property IOSTANDARD LVCMOS33 [get_ports {a_out_h_0[6]}]
set_property PACKAGE_PIN T12 [get_ports {a_out_h_0[7]}]
set_property IOSTANDARD LVCMOS33 [get_ports {a_out_h_0[7]}]
set_property PACKAGE_PIN W8 [get_ports {a_out_h_0[8]}]
set_property IOSTANDARD LVCMOS33 [get_ports {a_out_h_0[8]}]
set_property PACKAGE_PIN B19 [get_ports {a_out_h_0[9]}]
set_property IOSTANDARD LVCMOS33 [get_ports {a_out_h_0[9]}]
set_property PACKAGE_PIN A20 [get_ports {a_out_h_0[10]}]
set_property IOSTANDARD LVCMOS33 [get_ports {a_out_h_0[10]}]
set_property PACKAGE_PIN D19 [get_ports {a_out_h_0[11]}]
set_property IOSTANDARD LVCMOS33 [get_ports {a_out_h_0[11]}]
set_property PACKAGE_PIN V15 [get_ports {a_out_h_0[12]}]
set_property IOSTANDARD LVCMOS33 [get_ports {a_out_h_0[12]}]
set_property PACKAGE_PIN V8 [get_ports {a_out_h_0[13]}]
set_property IOSTANDARD LVCMOS33 [get_ports {a_out_h_0[13]}]
set_property PACKAGE_PIN F17 [get_ports {a_out_h_0[14]}]
set_property IOSTANDARD LVCMOS33 [get_ports {a_out_h_0[14]}]
set_property PACKAGE_PIN V7 [get_ports {a_out_h_0[15]}]
set_property IOSTANDARD LVCMOS33 [get_ports {a_out_h_0[15]}]
set_property PACKAGE_PIN T9 [get_ports {a_out_h_0[16]}]
set_property IOSTANDARD LVCMOS33 [get_ports {a_out_h_0[16]}]
set_property PACKAGE_PIN V13 [get_ports {a_out_h_0[17]}]
set_property IOSTANDARD LVCMOS33 [get_ports {a_out_h_0[17]}]
set_property PACKAGE_PIN V16 [get_ports ac_lo_in_h_0]
set_property IOSTANDARD LVCMOS33 [get_ports ac_lo_in_h_0]
set_property PACKAGE_PIN K17 [get_ports ac_lo_out_h_0]
set_property IOSTANDARD LVCMOS33 [get_ports ac_lo_out_h_0]
set_property PACKAGE_PIN D18 [get_ports bbsy_in_h_0]
set_property IOSTANDARD LVCMOS33 [get_ports bbsy_in_h_0]
set_property PACKAGE_PIN E17 [get_ports bbsy_out_h_0]
set_property IOSTANDARD LVCMOS33 [get_ports bbsy_out_h_0]
set_property PACKAGE_PIN W20 [get_ports {bg_in_l_0[4]}]
set_property IOSTANDARD LVCMOS33 [get_ports {bg_in_l_0[4]}]
set_property PACKAGE_PIN W16 [get_ports {bg_out_l_0[4]}]
set_property IOSTANDARD LVCMOS33 [get_ports {bg_out_l_0[4]}]
set_property PACKAGE_PIN P20 [get_ports {bg_in_l_0[5]}]
set_property IOSTANDARD LVCMOS33 [get_ports {bg_in_l_0[5]}]
set_property PACKAGE_PIN V20 [get_ports {bg_out_l_0[5]}]
set_property IOSTANDARD LVCMOS33 [get_ports {bg_out_l_0[5]}]
set_property PACKAGE_PIN U19 [get_ports {bg_in_l_0[6]}]
set_property IOSTANDARD LVCMOS33 [get_ports {bg_in_l_0[6]}]
set_property PACKAGE_PIN N20 [get_ports {bg_out_l_0[6]}]
set_property IOSTANDARD LVCMOS33 [get_ports {bg_out_l_0[6]}]
set_property PACKAGE_PIN U17 [get_ports {bg_in_l_0[7]}]
set_property IOSTANDARD LVCMOS33 [get_ports {bg_in_l_0[7]}]
set_property PACKAGE_PIN U18 [get_ports {bg_out_l_0[7]}]
set_property IOSTANDARD LVCMOS33 [get_ports {bg_out_l_0[7]}]
set_property PACKAGE_PIN T16 [get_ports {br_out_h_0[4]}]
set_property IOSTANDARD LVCMOS33 [get_ports {br_out_h_0[4]}]
set_property PACKAGE_PIN U15 [get_ports {br_out_h_0[5]}]
set_property IOSTANDARD LVCMOS33 [get_ports {br_out_h_0[5]}]
set_property PACKAGE_PIN Y14 [get_ports {br_out_h_0[6]}]
set_property IOSTANDARD LVCMOS33 [get_ports {br_out_h_0[6]}]
set_property PACKAGE_PIN W14 [get_ports {br_out_h_0[7]}]
set_property IOSTANDARD LVCMOS33 [get_ports {br_out_h_0[7]}]
set_property PACKAGE_PIN Y6 [get_ports {c_out_h_0[0]}]
set_property IOSTANDARD LVCMOS33 [get_ports {c_out_h_0[0]}]
set_property PACKAGE_PIN U10 [get_ports {c_out_h_0[1]}]
set_property IOSTANDARD LVCMOS33 [get_ports {c_out_h_0[1]}]
set_property PACKAGE_PIN G18 [get_ports {d_out_h_0[0]}]
set_property IOSTANDARD LVCMOS33 [get_ports {d_out_h_0[0]}]
set_property PACKAGE_PIN G19 [get_ports {d_out_h_0[1]}]
set_property IOSTANDARD LVCMOS33 [get_ports {d_out_h_0[1]}]
set_property PACKAGE_PIN H18 [get_ports {d_out_h_0[2]}]
set_property IOSTANDARD LVCMOS33 [get_ports {d_out_h_0[2]}]
set_property PACKAGE_PIN G17 [get_ports {d_out_h_0[3]}]
set_property IOSTANDARD LVCMOS33 [get_ports {d_out_h_0[3]}]
set_property PACKAGE_PIN K14 [get_ports {d_out_h_0[4]}]
set_property IOSTANDARD LVCMOS33 [get_ports {d_out_h_0[4]}]
set_property PACKAGE_PIN G20 [get_ports {d_out_h_0[5]}]
set_property IOSTANDARD LVCMOS33 [get_ports {d_out_h_0[5]}]
set_property PACKAGE_PIN J18 [get_ports {d_out_h_0[6]}]
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

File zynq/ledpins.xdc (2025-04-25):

set_property PACKAGE_PIN Y16 [get_ports LEDoutG_0]
set_property PACKAGE_PIN Y17 [get_ports LEDoutB_0]
set_property PACKAGE_PIN R14 [get_ports LEDoutR_0]
set_property IOSTANDARD LVCMOS33 [get_ports LEDoutB_0]
set_property IOSTANDARD LVCMOS33 [get_ports LEDoutG_0]
set_property IOSTANDARD LVCMOS33 [get_ports LEDoutR_0]

# set_property PACKAGE_PIN G15 [get_ports EXTSDA_0]   ;# CN2-69
# set_property PACKAGE_PIN H20 [get_ports EXTSCL_0]   ;# CN2-65
# set_property IOSTANDARD LVCMOS33 [get_ports EXTSDA_0]
# set_property IOSTANDARD LVCMOS33 [get_ports EXTSCL_0]

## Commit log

2025-04-25 initial commit
    - board works
    have to patch line BR6_OUT_H from J11-45 to J12-47/J5-14
    (J11-45 is connected to a 12MHz oscillator on ZTurn board)
    [bussigs.csv, zturn11.kicad_pcb, zturn11.kicad_sch]
2025-04-25 update pcb with patch for BG6_OUT_H
    also move power connector out from under zturn board
    [zturn11.kicad_pcb, zturn11.kicad_sch]
2025-04-25 add bunch of stuff
    add z11dump program, update pin list for pin command
    fpga: interrupt controller, little memory, serial line controller
2025-04-28 add diodes to the zturn11 board so the muxes work
    also add AC_LO_OUT_H and DC_LO_OUT_H drivers
    [zturn11.kicad_pcb, zturn11.kicad_sch]
2025-04-28 update zynq pin assignment files for new circuit board
    [bussigs.csv, zturnpins.csv]
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2025-05-04 start integrating simulator into fpga
    pin set fpgamode 1
    pin set sl_enable 1
    pin set sl_haltreq 1
    pin get sl_halted
    pin set lm_enab 1
    pin set lm_addr 0100
    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
2025-05-04 have fpgamode off reset all fpga circuitry
2025-05-05 add simple cpu test
    ./z11ctrl
    > source test.tcl
    > test1
    increments R0 and prints every 100mS
2025-05-06 replace 4KB lilmem.v with 248KB bigmem.v
    uses 50% of FPGA block memory
    [bigmem.v]
2025-05-06 add paper tape reader
    use test.tcl and test4 command to test it
    echoes paper tape reader to teletype printer
2025-05-10 get all mux lines working
    > pin set fpgamode 2
    > source memtest.tcl
    > testmuxbits
    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
2025-05-10 make csv files of bus signals within zynq.v
    [busses-real.csv, busses-sim.csv]
2025-05-10 get halt working
    doesn't seem to co-exist with front panel plugged in though
    $ ./z11ctrl
    z11ctrl> pin set fpgamode 2
    z11ctrl> hardreset
    z11ctrl> octal [rdword 0777776]
    000000
    z11ctrl> octal [rdword 0777707]
    000002
    z11ctrl> dumpmem 0100 0177
    000000 000000 000000 000000 000000 000000 000000 000000 000000 000000 000000 000000 000000 000000 000000 000000 : 000100
    000000 000000 000000 000000 000000 000000 000000 000000 000000 000000 000000 000000 000000 000000 000000 000000 : 000140
    z11ctrl> wrword 0100 05200
    z11ctrl> wrword 0102 0776
    z11ctrl> dumpmem 0100 0177
    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
2025-05-11 fix up halts and resets in scripts and simulator
    [pdp1134.v]
2025-05-15 add stepup.tcl script to trace ucode during processor startup
    - uses uc1134 board to step microcode
    uc1134 board must be plugged in and running as hostname zturn3
    also have bm_enables be settable during businit
    so they can be set when processor is shut off
    1) plug boards in and turn on
2025-05-16 add parity to bigmem
    but it doesn't report errors to pdp yet
    [bigmem.v]
2025-05-16 update scripts for halting
    ...still not correct
    reset then halt:
    z11ctrl> pin set sl_haltreq 1
    z11ctrl> pin set man_ac_lo_out_h 1 man_dc_lo_out_h 1
    z11ctrl> pin set man_dc_lo_out_h 0 man_ac_lo_out_h 0
    ...but doesn't resume when sl_haltreq negated
    reset then run:
    z11ctrl> pin set sl_haltreq 0
    z11ctrl> pin set man_ac_lo_out_h 1 man_dc_lo_out_h 1
    z11ctrl> pin set man_dc_lo_out_h 0 man_ac_lo_out_h 0
    ...seems to start up ok
2025-05-19 get swlight.v dma working
    test script:
    source inclooptest.tcl
    start ;# gets is running
    loop ;# does a dma transfer every 200mS
2025-05-19 get fpga single-stepper working
    also fix up some z11ctrlini.tcl scripts
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2025-05-23 fix dma access while processor running
    use separate del_msyn_in_h and syn_msyn_in_h in swlight.v
    dma must not start unless syn_msyn_in_h and syn_ssyn_in_h are idle
    ...as it is possible it never sees del_ssyn_in_h for cycle between
    processor and boot rom (or external memory)
    test:
    setup is pdp with boot rom board, no memory, no cache
    $ make dmaloop.armv7l
    > pin set bm_enablo 0xffff
    > hardreset
    (start z11dl on another terminal)
    > flickstart 0165020
    (tty should prompt nnnnnn nnnnnn nnnnnn nnnnnn crlf @)
    >
    (start dmaloop.armv7l on another terminal)
    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
2025-05-23 get interrupts working
    > source inttest.tcl
    > loadtest
    > runtest
    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
2025-05-24 get basic RL11 test working
    $ ../MACRO11/src/macro11 -o rltest.obj -l rltest.lst rltest.mac
    > pin set bm_enablo 0xffffffff
    on other screen $ z11rl_debug=1 ./z11rl -loadrw 0 ~/disk0.rl02
    on other screen $ ./z11dl -cps 960
    > loadlst rltest.lst
    > flickstart 0400
    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
2025-05-25 get simulator working with rltest.mac
    see top of rltest.mac for test
    use 'pin set fpgamode 1' instead of ... 2
2025-05-26 gray out GUI buttons based on running/halted
    also distinguish halted with halt/step buttons vs halt instruction/double trap
    halt/step buttons allow continue
    halt instruction/double trap do not
2025-05-30 get dfkaa maindec working with simmer simulator
    $ ./simmer.x86_64 on one screen
    $ ./z11dl -cps 960 on second screen
    $ ./z11dump on third screen
    $ ./z11ctrl on fourth screen
    > pin set fpgamode 1 bm_enablo 0xffffffff
    > loadbin dfkaa.bin
    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
2025-05-30 add disassemble command
    and a couple fixups for simmer
2025-05-30 fixes for sim1134.v working with maindec dfkaa
    > pin set fpgamode 1 bm_enablo 0xFFFFFFFF
    > wrword 0777707 0200
    > steptraceloop
    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
2025-05-31 finish getting sim1134.v working with maindec dfkaa
    on one screen:
    $ z11dl
    on another:
    $ z11ctrl
    > flickstart 0200
    should print 'END OF DFKAA-B' every second or so
    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
2025-06-01 get out-e-11 to boot in simmer
    needed edge trigger interrupts
    $ ../simmer/simmer.x86_64 &
    > pin set fpgamode 1
    > pin set bm_enablo 0xFFFFFFFF bm_enabhi 0x3FFFFFFFF
    > pin set kl_enable 1
    > pin set sl_enable 1
    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
2025-06-01 fix KL-11 interrupt request so RT-11 boots
    > source testrt11.tcl
    > rt11initsim .. to use simmer or sim1134 simulator
    > rt11boot
    > rt11initreal .. to use real PDP with memory
    > rt11boot
    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
2025-06-02 make muxdelay programmable
    test with rltest.tcl script
    18 doesn't work, 19 works, so set default to 21 (210nS)
    > pin set muxdelay 19
    > source rltest.tcl
    > pin set muxdelay 18 ;# hangs
    monitor with z11dump
    $ ./z11dump
    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
2025-06-03 get memory parity checking working
    defines a M7850-like board for FPGA memory (bigmem.v)
    should also work with a real M7850 for real memory
2025-06-05 have line clock interrupt on low-to-high edge
    ...regardless of flag bit state
    ie, don't require program to clear flag to get another interrupt
    rsx now boots on sim1134.v sim and real pdp
    > pin set fpgamode 1 or 2 ;# 1 for sim1134.v sim; 2 for real pdp
    > rsx.tcl
    doesn't seem to work on simmer sim
    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
2025-06-07 add BOOT button to GUI screen
    spawns guiboot.sh script to do the actual booting
2025-06-07 make sure only one GUI BOOT button process running at a time
    also clean up rsx boot script a little
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2025-06-08 get GUI panel looking pretty good
    uses the neon-type circles for buttons, switches and lights
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2025-06-08 add simulated device control checkboxes to GUI screen
    set fpgamode, set DL,KW,KY device enables
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2025-06-09 get GUI things to fit better
    removed border from leds
    buttons are exactly 2 x led size
2025-06-09 fix GUI button and switch background to stay even when pressed
    ...otherwise it went gray
2025-06-09 fix recovery from dma timeout
    it left address, control, data lines jammed up
    boot rsx or similar
    halt with GUI panel
    load address 0760000
    examine, observe BERR light
    continue booted OS, it should resume
    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
    [ky11.v]
2025-06-09 put all 18 switch register bits in the FPGA
    so the top 2 bits behave consistently in the GUI with the lower 16 bits
2025-06-10 add rl02 file chooser to GUI RL02 LOAD button
    and prefix filenames with current directory
    and compress out /../ and /./
2025-06-11 add boot rom capability to bigmem
    512-byte enable bits for address range 760000..777777
    can also jam address in that range during power-up cycle for power-up vector
    [bigmem.v]
2025-06-12 have bigmem boot mem jamming accept PC,PS reading in either order
    [bigmem.v]
2025-06-12 get rlboot.tcl to work with real M7859 and M9312 plugged in
    boots the RL01/2 drive regardless of whether the M9312 has an RL boot ROM
    cable from M7859 to console lights/switches plugged in
    cable from M9312 to console lights/switches plugged in
    must have M9312 SW 1-2 set to OFF
    lest it jimmy the power-on vector to 773024
    whilst rlboot.tcl tries to jimmy it to 761024
    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
2025-06-12 have GUI tolerate running with real KY-11 installed
    uncheck the [ ]KY-11 checkbox
    only allows RESET and BOOT buttons to work
    all other functions must be done on real KY-11 buttons
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2025-06-12 double click GUI RESET button instead of are you sure box
    also blank out PHYS/VIRT of address label when KY-11 disabled
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2025-06-13 simplify GUI button enables
    simplify line clock enable
    reduce fpga mode select to single checkbox
2025-06-13 make a boot menu for the GUI boot button
    prompts on tty for what to boot
    consolidates the device probing and startup into one script
    also rename GUI to z11gui for more consistent naming
2025-06-16 fpu over-the-top 20-pin connector board
    replacement for cpu<->fpu ucode address connector
    [fpott20.kicad_pcb, fpott20.kicad_sch]
2025-06-17 have paper tape reader generate interrupt when setting GO with ERROR
    also use error bits to indicate absence of tape in reader and/or punch
2025-06-20 use interrupts from fpga->arm to trigger RL I/Os
    and set up fastio flag so RL will skip its usleeps()
2025-06-20 add turbo mode flag to zynq.v and sim1134.v
    skips dma cycle delays, only used for sim mode
    [ky11.v]
2025-06-20 add tooltip text for gui buttons
    and long-press on RESET avoids confirmation prompt
2025-06-22 shorten KY-11 DMA end cycle delays from 150nS to 80nS
    the 150nS delay only applies to MSYN at beginning of cycle
    [ky11.v]
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2025-06-28 little fixes to work with rsx autogen
    dz-11 and tm-11 work
    [dz11.v]
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2025-06-29 fix ky-11 step function with cache board
    also fix a bunch of lint things found with verisim
    [dz11.v, ky11.v]
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2025-07-02 have snapregs work when processor already halted
    snapregs always sets haltreq when it starts to halt processor while it reads registers
    it used to always clear haltreq when it finished to let the processor continue
    now it can either leave haltreq set or clear haltreq when it finishes
    [ky11.v]
2025-07-02 fix starting gui when fpga is off
    dmalock() would hang because ky11.v dmalock held at 0
    also fix that gui buttons just flashed when pressed
    now stay lit as long as held down
    [ky11.v]
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2025-07-08 fix tm11 rewind/unload status not resetting
    also update current tape position continuously while rewinding for gui
    and add -create option to tmload to create an empty tape file
    [shmms.h]
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2025-07-16 get rsx4.5 decnet working with delua
    - change z11xe from deuna to delua
    decnet uploads mystery microcode to deuna but leaves delua as is
    - reset should set DNI when complete
    - fill in source address when transmitting packet
    - do level-triggered interrupts instead of edge-triggered
    - support loopback mode
    - support enable-all-multicast mode
    - add -killit option to z11xe to kill old z11xe process
    - use standard digital mac prefix 08:00:2B for default address
    and default the low 3 bytes to hardware ethernet's mac address
    - added simtrace program to trace sim bus cycles
2025-07-18 redo dmalock/dmaunlk with a shared memory futex
    ky_dmalock didn't work
    boot rsx45/dlsym.rl02 disk
    test with 'dnping pdp11' loop on pdpi
    do 'pip [*,*]/li' on the pdp11
    - ran it for 45 mins
    used to fail in just a couple mins
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2025-07-25 don't reset RH-11 MOL,WRL,DT bits on bus init
    also fix disk name in rsx45sysgen-rp04.tcl script
    [rh11.v]
2025-07-26 fix z11xe locking xe fpga registers with -daemon option
    also change uid/gid back to caller after opening raw socket
2025-07-30 fix up rh-11 controller seek timing and pip bit
    [rh11.v]
2025-08-01 don't clear rh11 vol valid on controller clear function
    ...only clear on fpga power-up/reset or file load
    [rh11.v]
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2025-08-14 fix z11xe to default ethernet to first 'e' network device
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2025-08-18 updates for pidp interface
    move pidp led update into separate thread
    ...so they update consistentently regardless of network latencies
    fix up cont & start switch processing
    update ADDR16/18, KERNEL/USER LEDs
    [z11pidp.cc]
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2025-08-23 fix up halt instruction in presence of z11pidp server running
    [ky11.v, z11pidp.cc]
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2025-09-13 add ky2_snapblk to block snapregs usage
    for use by maindec scripts when the z11gui and z11pidp programs interfere
    [ky11.v, z11pidp.cc]
2025-09-24 fix simulator power-up vector reading initial PSW
2025-09-30 add rollights.mac demo program
    rolls address & data lights on z11gui or z11pidp panel
    use switch register to determine number of steps between direction reversals

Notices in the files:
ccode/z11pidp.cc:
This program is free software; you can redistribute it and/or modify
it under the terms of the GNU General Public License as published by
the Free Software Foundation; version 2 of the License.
